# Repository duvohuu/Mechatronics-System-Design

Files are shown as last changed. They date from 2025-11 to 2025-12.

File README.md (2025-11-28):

# BÁO CÁO
- Section → Subsection → Subsubsection → Dot → '-' → '+'

## Cấu trúc thư mục ảnh
Tất cả ảnh đặt trong thư mục chính `pictures/`. Mỗi chương có một thư mục con chứa ảnh của chương đó.

Cấu trúc:
- pictures/
  - section_1/
  - section_2/
  - section_3/
  - ...

Quy ước đặt tên tệp ảnh:
- Định dạng: cx_py_abc.ext
  - c: ký tự 'c' (chỉ section)
  - x: số chương (ví dụ 1, 2, 10)
  - _p: phân cách và chữ 'p' (picture)
  - y: số thứ tự ảnh trong chương (ví dụ 01, 02; khuyến khích 2 chữ số)
  - _abc: mô tả ngắn về nội dung (không dấu, dùng underscore để cách)
  - .ext: phần mở rộng (png, jpg, pdf, ...)

Ví dụ:
- c1_p01_overview.png      (Ảnh 1 của chương 1, mô tả: overview)
- c2_p03_topography.jpg    (Ảnh 3 của chương 2, mô tả: topography)
- c10_p12_cross_section.pdf

## Template cho hình ảnh:
```latex
\begin{figure}[H]
    \centering
    \includegraphics[width=1\textwidth]{pictures/image.png}
    \caption{Mô tả hình ảnh}
    \label{fig:label}
\end{figure}
```

## Template cho bảng:
```latex
\begin{table}[H]
    \centering
    \begin{tabular}{|c|c|c|}
        \hline
        \textbf{Cột 1} & \textbf{Cột 2} & \textbf{Cột 3} \\
        \hline
        Dữ liệu 1 & Dữ liệu 2 & Dữ liệu 3 \\
        \hline
    \end{tabular}
    \caption{Mô tả bảng}
    \label{tab:label}
\end{table}
```

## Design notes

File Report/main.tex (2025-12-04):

\documentclass[12pt,a4paper]{report}
\input{library}
\addbibresource{references.bib} 

%Header
\fancyhead{} % clear all header fields
\fancyhead[L]{
    \begin{tabular}{rl}
        \begin{picture}(15, 15)(0,0)
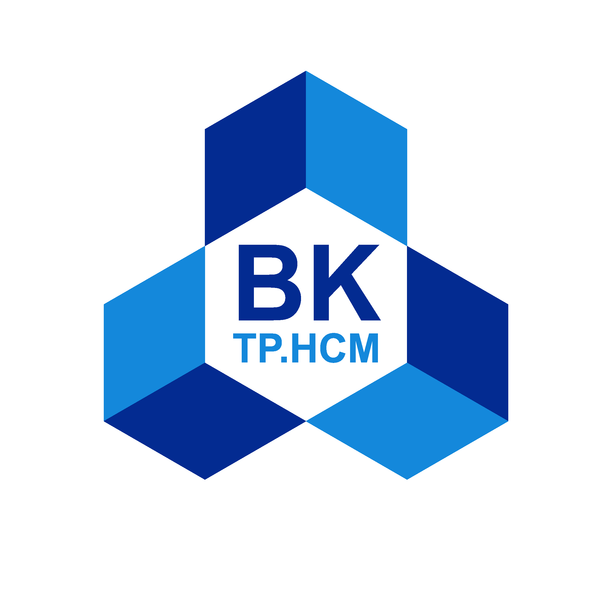
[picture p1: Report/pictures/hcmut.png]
            \put(-15, -15){}
        \end{picture}
        \begin{tabular}{l}
            \textbf{\bf \ttfamily Trường Đại Học Bách Khoa - ĐHQG TP.HCM}\\
            \textbf{\bf \ttfamily Thiết kế hệ thống Cơ điện tử}\\
        \end{tabular} 	
    \end{tabular}
}
\fancyhead[R]{CHƯƠNG \thechapter}
% Footer
\fancyfoot[C]{\thepage} % số trang giữa
\renewcommand{\headrulewidth}{0.3pt}
\renewcommand{\footrulewidth}{0.3pt}

\begin{document}
    \include{titlepage}
    \tableofcontents  
    \listoftables
    \listoffigures
    \newpage
    \normalsize
    \include{chapter1}
    \include{chapter2}
    \include{chapter3}
    \include{chapter4}
    \include{chapter5}
    % \include{chapter6}
    % \appendix
    % \include{appendixA}
    \nocite{*}
    \printbibliography[title={TÀI LIỆU THAM KHẢO}, heading=bibintoc]
\end{document}

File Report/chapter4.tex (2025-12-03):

\chapter{THIẾT KẾ HỆ THỐNG ĐIỆN}
     \hspace*{0.6cm}Yêu cầu thiết kế hệ thống điện dựa trên TCVN-7802-1:2007
     \begin{itemize}
          \item Dải hoạt động của thiết bị đo lường lực: 1.2 kN đến 20 kN
          \item Độ chính xác của thiết bị đo lường lực: $\pm 2 \%$
     \end{itemize}
     \hspace*{0.6cm}Từ việc lựa chọn các phương án điện tổng quát, sơ đồ kết nối điện tổng thể của máy được thể hiện như hình dưới. Sơ đồ thể hiện cách các thiết bị kết nối với nhau, từ nguồn cấp điện đến tủ điều khiển, cảm biến, động cơ. Các model cụ thể cho từng thiết bị cũng như việc tính toán an toàn điện, lựa chọn các thiết bị bảo vệ sẽ được trình bày chi tiết trong chương này.
     \begin{figure}[H]
          \centering
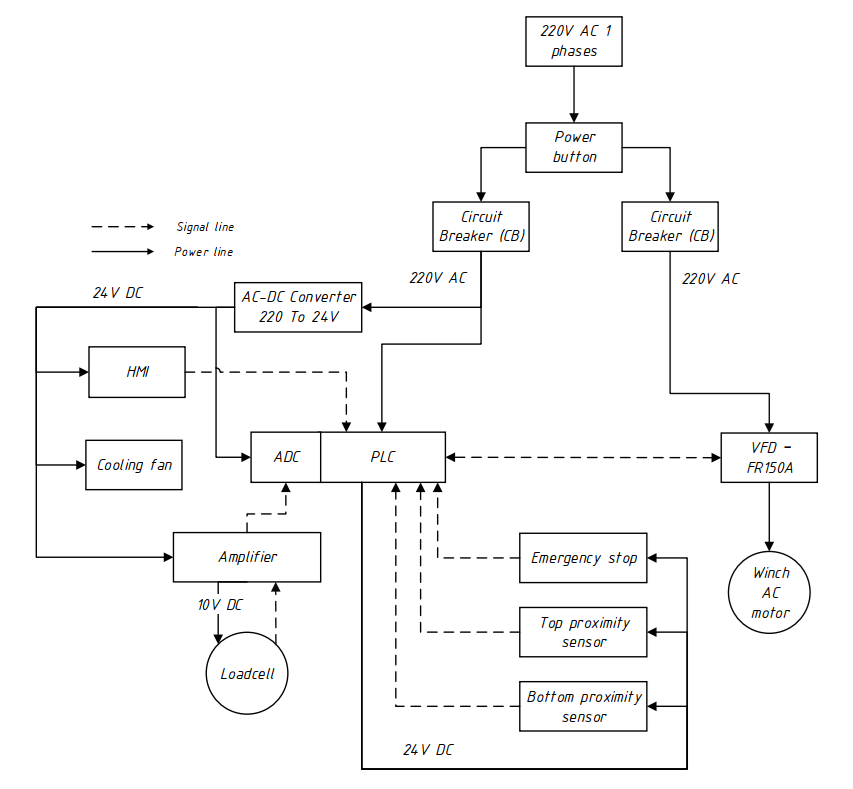
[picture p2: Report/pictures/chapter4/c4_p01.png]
          
          \caption{Sơ đồ điện tổng quan của hệ thống}
          \label{c4_p01}
     \end{figure}
     % Nội dung
     \section{Lựa chọn thiết bị}
          \subsection{Bộ điều khiển PLC và module mở rộng}
               \hspace*{0.6cm}Bộ điều khiển logic khả trình - Programmable Logic Controller (PLC) là trung tâm của hệ thống điều khiển. chịu trách nhiệm xử lý dữ liệu đầu vào, thực thi logic điều khiển và quản lý dữ liệu đầu ra để đảm bảo máy hoạt động chính xác. Để lựa chọn PLC phù hợp, cần xem xét đến các yêu cầu về hiệu suất và khả năng giao tiếp như sau
               \begin{itemize}
                    \item Nguồn cấp: Tương thích với nguồn điện tiêu chuẩn công nghiệp (220 VAC cho nguồn chính, sử dụng bộ chuyển đổi nội hoặc nguồn ngoài cấp 24V DC cho mạch logic).
                    \item I/O: PLC cần có đủ các chân ngõ vào kĩ thuật số (DI) và ngõ ra kĩ thuật số (DO) để kết nối với toàn bộ cảm biến, công tắc và phát tín hiệu điều khiển. Yêu cầu tối thiểu đối với hệ thống: 7 ngõ vào (2 cảm biến tiệm cận, nút nhấn dừng khẩn cấp, tín hiệu từ HMI) và 3 ngõ ra (cho lệnh chạy VFD, điều khiển chiều quay và tốc độ gửi xuống VFD).
                    \item Chức năng đặc biệt: Hỗ trợ bộ đếm tốc độ cao (High-speed Counter) và ngõ ra xung (Pulse Output).
                    \item Truyền thông: Có ít nhất 1 chuẩn giao thức truyền thông (RS232, RS485, RS422, Ethernet) để kết nối với HMI.
                    \item Ngõ vào analog: PLC có khả năng đọc tín hiệu analog, thông qua các ngõ vào có sẵn hoặc module mở rộng nhằm đọc tín hiệu từ bộ khuếch đại tín hiệu loadcell.
                    \item Khả năng xử lí: Cần khả năng xử lí số thực (floating-point) nhằm cho việc tính toán bộ điều khiển PID và các tác vụ xử lí dữ liệu khác.
                    \item Độ tin cậy và giá thành: Độ bền cao trong môi trường công nghiệp, khả năng chống nhiễu tốt và chi phí hợp lí.
               \end{itemize}
               \hspace*{0.6cm}Dựa trên quá trình lựa chọn và đánh giá thỏa mãn các yêu cầu phía trên, PLC MItsubishi FX3U-16MT/ES-A được lựa chọn. Dòng FX3U được đánh giá cao nhờ độ tin cậy, khả năng xử lí và mở rộng trong các hệ thống tự động hóa công nghiệp. Kí hiệu "16MT" trên tên PLC thể hiện PLC có 8 ngõ vào số và 8 ngõ ra transistor, đáp ứng đủ như cầu về các chân I/O. PLC này cũng hỗ trợ xử lí số thực và có sẵn cổng truyền thông RS422 để kết nối với màn hình HMI.
               \newline
               \hspace*{0.6cm}Tuy nhiên dòng FX3U không tích hợp sẵn đầu vào analog, do đó để nhận tín hiệu đầu ra từ bộ khuếch đại tín hiệu loadcell (0 - 10V). Do đó cần thiết phải sử dụng thêm 1 bộ ADC (Analog-to-Digital Converter) mở rộng. Mitsubishi FX3U-3A-ADP được lựa chọn vì nó được thiết kế chuyên dụng để sử dụng với dòng FX3U, cung cấp các kênh ngõ vào analog cần thiết để chuyển đổi tín hiệu analog thành tín hiệu số phục vụ cho việc tính toán trong chương trình điều khiển của PLC.
               \begin{figure}[H]
                    \centering
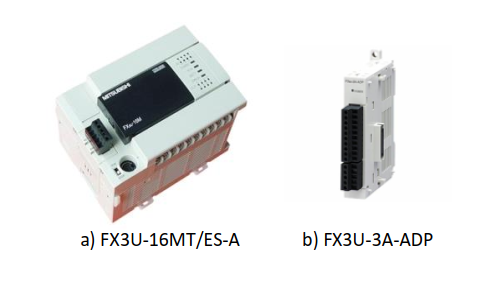
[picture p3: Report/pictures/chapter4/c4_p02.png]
                    
                    \label{c4_p02}
               \end{figure}
               \subsection{Cảm biến loadcell và bộ khuếch đại}
               \hspace*{0.6cm}Độ chính xác khi đo lường lực trong quá trình hoạt động của máy thử thiết bị rất quan trọng, do đó cần 1 cảm biến loadcell đáng tin cậy để chuyển đổi tín hiệu điện thành tín hiệu điện áp, cùng với một bộ khuếch đại tín hiệu để khuếch đại tín hiệu nhằm tương thích với dải đọc analog trên PLC. Các tiêu chí để lựa chọn như sau
               \begin{itemize}
                    \item Tương thích với nguồn cấp: hoạt động với nguồn cấp điện áp 24VDC
                    \item Dải đo: Chịu được lực kéo tĩnh khoảng 15 kN, đồng thời chịu được tải tối đa thiết bị test yêu cầu lên đến 20 kN, tương đương với tải trọng khoảng 2000 kb ($\approx 20 \mathrm{kN}$)
                    \item Độ chính xác: Hệ cảm biến cần có độ chính xác $< \pm 2 \%$
                    \item Tín hiệu ngõ ra: Bộ khuếch đại tín hiệu loadcell cần cung cấp đầu ra là tín hiệu analog chuẩn hóa (0-10 V hoặc 4-20 mA).
               \end{itemize}
               \hspace*{0.6cm}Với những yêu cầu trên, cộng với quyết định sử dụng loadcell loại S ở chương 2 vì phù hợp với thử nghiệm kéo (tensile testing) và dễ dàng lắp đặt, loadcell PT4000 được lựa chọn sử dụng. Loại có định mức từ 2000 kg trở lên đáp ứng được dải tải yêu cầu, đảm bảo độ tin cậy và độ chính xác phù hợp.
               \newline
               \hspace*{0.6cm}Để khuếch đại tín hiệu từ loadcell, lựa chọn bộ khuếch đại KM02. Bộ khuếch đại này hoạt động trong dải điện áp 15-24 VDC. KM02 cung cấp tín hiệu đầu ra có thể cấu hình (0-10 V hoặc 4-20 mA) tương thích với module analog của PLC. Ngoài ra nó còn được tích hợp sẵn các chiết áp để điều chỉnh đầu ra ở các mức ZERO và SPAN, giúp quá trình hiệu chỉnh trở nên đơn giản, chính xác và thuận tiện.
               % figure
          \subsection{Cảm biến tiệm cận}
               \hspace*{0.6cm}Để ngăn ngừa hư hỏng cơ khí và đảm bảo vận hành an toàn, máy phải phát hiện được giới hạn trên và giới hạn dưới của cơ cấu tời (winch mechanism) hoặc các bộ phận chuyển động khác. Cảm biến tiệm cận điện cảm (inductive proximity sensor) là lựa chọn lý tưởng để phát hiện các mục tiêu kim loại mà không cần tiếp xúc vật lý. Các tiêu chí lựa chọn cảm biến này bao gồm:
               \begin{itemize}
                    \item Nguồn: Hoạt động ở 24 V DC, tiêu chuẩn cho các hệ thống điều khiển công nghiệp.
                    \item Loại đầu ra: Cấu hình PNP 3 dây, phù hợp để kết nối với các module đầu vào sourcing của PLC Mitsubishi.
                    \item Khoảng cách cảm biến: Khoảng 5–10 mm để đảm bảo hoạt động tin cậy mà không yêu cầu định vị quá chính xác.
                    \item Mục tiêu phát hiện: Phải phát hiện đáng tin cậy các vật thể kim loại.
                    \item Cách lắp đặt: Thân trụ ren (loại gắn bằng đai ốc) để dễ dàng lắp đặt cơ khí.
                    \item Độ bền và tính sẵn có: Chịu được môi trường công nghiệp khắc nghiệt, sử dụng thường xuyên và dễ thay thế.
               \end{itemize}
               \hspace*{0.6cm}Dựa trên các tiêu chí trên, cảm biến tiệm cận điện cảm model LJ18A3-8-Z/BY PNP đã được lựa chọn. Model này có thân ren M18 tiện lợi cho việc lắp đặt, hoạt động với nguồn 24 V DC, đầu ra loại PNP (lưu ý: có thể kết nối tương thích với đầu vào sourcing của PLC bằng cách đấu nối phù hợp). Khoảng cách cảm biến 8 mm nằm trong dải mong muốn để phát hiện các chốt chặn kim loại. Cảm biến này có giá thành hợp lý, được sử dụng rộng rãi và chứng minh độ tin cậy cao trong môi trường công nghiệp.
          \subsection{Biến tần}
               \hspace*{0.6cm}Máy thử nghiệm sử dụng tời điện được dẫn động bởi động cơ điện AC nhằm tạo ra và duy trì lực kéo. Do yêu cầu của bài thử nghiệm cần tăng lực từ từ (trong vòng 240s) và duy trì (trong vòng 180s), phương pháp điều khiển ON/OFF đơn giản không thể đáp ứng. Vì vậy, việc sử dụng biến tần (VFD: Variable Frequency Drive) là cần thiết do mục đích điều khiển chính xác tốc độ, moment, xoắn, việc gia tốc, giảm tốc và chiều quay của động cơ dựa trên giá trị setpoint từ bộ điều khiển PID.
               \newline
               \hspace*{0.6cm}Các yêu cầu kĩ thuật:
               \begin{itemize}
                    \item Tương thích với nguồn: Biến tần hỗ trợ nguồn 1 pha 220 VAC.
                    \item Công suất định mức: phải đủ khả năng dẫn động động cơ điện công suất 1.4 kW cho tời kéo. 
                    \item Khả năng tích hợp với PLC: Hỗ trợ giao tiếp số (ưu tiên giao thức Modbus) để giao tiếp lệnh điều khiển và dữ liệu phản hồi giữa PLC và biến tần.                 
               \end{itemize}                
               \hspace*{0.6cm}Mẫu biến tần được lựa chọn là FR150A-2S-1.5B-H của hãng Frecon Electric, đáp ứng được tất cả các yêu cầu trên. Biến tần này có công suất định mức 1.5 kW, hoạt động với nguồn vào 220 V một pha, đủ để dẫn động động cơ tời 1.4 kW.
               Đặc biệt quan trọng, model này hỗ trợ giao thức Modbus RTU qua RS485, cho phép PLC Mitsubishi FX3U gửi các lệnh điều khiển (như chạy/dừng, đặt tần số, đặt hướng quay...) và nhận dữ liệu phản hồi (tốc độ động cơ thực tế, dòng điện, trạng thái lỗi, v.v.).
               Nhờ đó, hệ thống đạt được khả năng điều khiển lực tời chính xác, lập trình linh hoạt và vận hành ổn định, đáng tin cậy.
          \subsection{HMI}
               \hspace*{0.6cm}Giao diện người-máy HMI (Human-Machine Interface) cho phép người vận hành thực hiện các thao tác với hệ thống như khởi động/dừng quá trình thử nghiệm, cài đặt các thông số bộ điều khiển (hệ số PID, các hệ số hiệu chỉnh, \dots), theo dõi dữ liệu thời gian thực (giá trị lực, thời gian, trạng thái cảm biến), hiển thị đồ thị kết quả thử nghiệm (đồ thị lực theo thời gian). Các tiêu chí để lựa chọn HMI bao gồm:
               \begin{itemize}
                    \item Giao tiếp với PLC: Đảm bảo kết nối được với PLC Mitsubishi FX3U-16MT/ES-A.
                    \item Màn hình hiển thị: Kích thước và độ phân giải đủ lớn, hỗ trợ cảm ứng để dễ dàng thao tác.
                    \item Phần mềm: Dễ dàng sử dụng trong việc thiết kế giao diện và gửi nhận dữ liệu với PLC. 
               \end{itemize}
               Từ các tiêu chí đó, lựa chọn HMI Weintek MT607iH. HMI có màn hình 7 inch, độ phân giải của màn hình là $800 \times 400$. Hỗ trợ kết nối với PLCs qua giao thức RS232 và RS485. Cấu hình HMI thực hiện thông qua phần mềm EasyBuilder Pro (hoặc EasyBuilder 8000) giúp thiết kế giao diện HMI dễ dàng.
     \section{Tính toán nguồn và an toàn thiết bị điện}
          \subsection{Nguồn động lực}
          \hspace*{0.6cm}Từ sơ đồ khối điện tổng quát, các nguồn chính là: nguồn xoay chiều 1 pha 220 VAC cho tời điện và biến tần, nguồn 1 chiều 24 VDC cho các thiết bị còn lại.
          \subsection{Tính toán dây dẫn}
          \hspace*{0.6cm}Dựa trên các thiết bị dã chọn, tiến hành tính toán dòng điện, lựa chọn dây dẫn, các thiết bị bảo vệ. Bảng dưới đây liệt kê các thiết bị điện trong hệ thống, số lượng và công suất tiêu thụ điện
          \begin{table}[h!]
               \caption{Danh sách thiết bị}
               \label{tab:device_list}
               \centering
               \begin{tabular}{|c|l|c|c|c|}
               \hline
               \textbf{} & \centering\textbf{Tên thiết bị} & \textbf{Số lượng} & \textbf{Nguồn} & \textbf{Công suất tiêu thụ} \\ \hline

               1 & PLC FX3U-16MT/ES-A & 1 & \multirow{5}{*}{24V DC} & 30\,W \\ \cline{1-3}\cline{5-5}

               2 & Module FX3U–3A–ADP & 1 &  & 5\,W \\ \cline{1-3}\cline{5-5}

               3 & Weintek HMI model MT607iH & 1 &  & 6\,W \\ \cline{1-3}\cline{5-5}

               4 & Bộ khuếch đại BRT RW-ST01A & 1 &  & 1.5\,W \\ \cline{1-3}\cline{5-5}

               5 & Cảm biến tiệm cận LJ18A3-8-Z/BX NPN & 1 &  & 7.2\,W \\ \hline

               6 & Tời điện 3WG4 Atlas II 
               & 1 & \multirow{2}{*}{220V AC} & 1.4\,kW \\ \cline{1-1}\cline{2-3}\cline{5-5}

               7 & Biến tần FR150A-2S-1.5B-H & 1 &  & 1.5\,kW \\ \hline
               \end{tabular}
          \end{table}
          \hspace*{0.6cm}Dòng trong mạch điều khiển
          \begin{equation}
               I_{\text{control}} = \dfrac{P}{U} = \dfrac{30 + 5 + 6 + 1.5 + 7.2}{24} \approx 2.07 \,\mathrm{A}
               \label{c4_eq01}
          \end{equation}
          \hspace*{0.6cm}Đối với mạch điều khiển, sử dụng bộ chuyển đổi nguồn 24V 3A 72W.
          \newline
          \hspace*{0.6cm}Tính toán dòng cho CB trong mạch điều khiển
          \begin{equation}
               I_{\text{control\_CB}} = (1.2 \div 1.5)I_{\text{control}} = 2.07 \times 1.5 \approx 3.105 \,\mathrm{A}
               \label{c4_eq02}
          \end{equation}
          \hspace*{0.6cm}Với dòng như vậy, lựa chọn MCB Chint NXB-63 C6 2P làm CB cho mạch điều khiển.
          \newline
          \hspace*{0.6cm}Đối với mạch động lực, dòng đầu vào định mức của biến tần Frecon FR150A-2S-1.5B-H là 15.7 A, tiến hành tính toán dòng cho CB mạch động lực 
          \begin{equation}
               I_{\text{power\_CB}}  = (2 \div 3)I_{\text{power}} = 15.7 \times 3 = 47.1 \,\mathrm{A}
               \label{c4_eq03}
          \end{equation}
          \hspace*{0.6cm}Với dòng tính toán, lựa chọn MCB 2P 50A, 63A 6kA Panasonic làm CB cho mạch động lực.
          \newline
          \hspace*{0.6cm}Về dây dẫn đấu nối trong mạch, tra theo Catalogue của Cadivi, các loại dây sử dụng được liệt kê ở bảng sau
          \begin{table}[H]
               \caption{Danh sách các loại dây sử dụng}
               \label{tab:wire_list}
               \centering
               \begin{tabular}{|l|c|}
               \hline
               \textbf{Chức năng dây} & \textbf{Loại dây} \\ \hline

               Dây cho 220VAC (Dây nóng – L) & VCm-2.5 \\ \hline
               Dây cho 220VAC (Dây trung tính – N) & VCm-2.5 \\ \hline
               Dây nối đất (PE) & VCm-1 \\ \hline
               Dây 24VDC (Dương) & VCm-1 \\ \hline
               Dây 24VDC (Âm) & VCm-1 \\ \hline
               Dây trong mạch điều khiển & VCm-1 \\ \hline
               \end{tabular}
          \end{table}

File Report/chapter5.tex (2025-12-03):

\chapter{THIẾT KẾ BỘ ĐIỀU KHIỂN}
    \textbf{Yêu cầu hệ thống}: Có khả năng tăng lực lên 15 kN trong vòng 240 giây và duy trì lực đó trong 180 giây.
    \section{Chương trình chính}
        \hspace*{0.6cm}Trong số các phương án được đề xuất, sơ đồ thuật toán của bộ điều khiển chính đã lựa chọn thể hiện đầy đủ các chức năng cần thiết cho quá trình vận hành của máy. Sơ đồ cung cấp cái nhìn rõ ràng và chi tiết về trình tự làm việc, giúp đảm bảo các bước được tổ chức logic, dễ theo dõi và tuân thủ đúng tiêu chuẩn yêu cầu. Nhờ đó, hệ thống vận hành ổn định, nhất quán và đạt độ chính xác cao.
        \begin{figure}[H]
            \centering
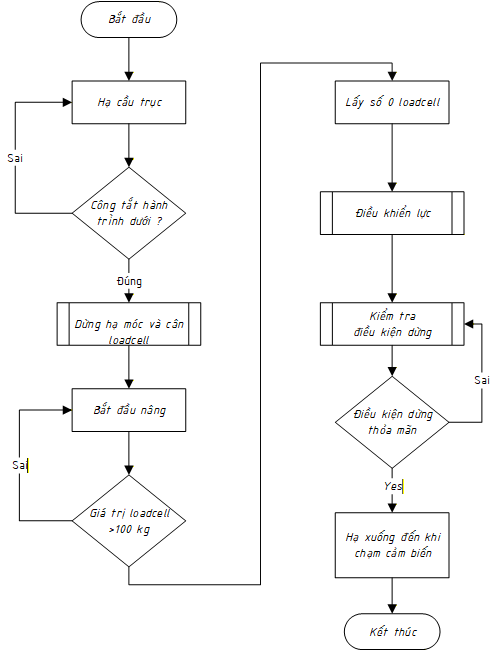
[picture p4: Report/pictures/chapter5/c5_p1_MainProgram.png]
            
            \caption{Sơ đồ chương trình chính}
            \label{fig:main_program}
        \end{figure}
        
        Chu trình hoạt động của máy thử độ bền tĩnh bắt đầu bằng lệnh hạ cụm nâng chính (cầu trục). Việc hạ diễn ra cho đến khi cảm biến hành trình dưới được kích hoạt, cho biết móc treo đã ở đúng vị trí thấp an toàn để gắn mẫu thử — ma nơ canh 100 kg. Khi cảm biến này báo hiệu, hệ thống lập tức dừng hạ.

        Tiếp theo, hệ thống tiến hành hiệu chỉnh loadcell về mốc zero, sử dụng trọng lượng của ma nơ canh làm giá trị chuẩn ban đầu. Việc hiệu chuẩn này giúp các phép đo lực sau đó chỉ phản ánh lực kéo tác dụng lên dây an toàn, không bao gồm trọng lượng của mẫu thử.

        Khi hiệu chuẩn hoàn tất, máy chuyển sang giai đoạn nâng tải. Tời bắt đầu kéo ma nơ canh lên, tạo lực căng trên dây an toàn. Hệ thống đồng thời kiểm tra giá trị loadcell để xem lực đo được có vượt mức ban đầu (100 kg) hay chưa. Nếu lực vượt ngưỡng này, điều đó chứng tỏ dây an toàn đã bắt đầu chịu lực thử.

        Từ thời điểm đó, bộ điều khiển sử dụng phản hồi từ loadcell và điều khiển động cơ tời thông qua VFD để tăng dần lực kéo, theo đúng yêu cầu tiêu chuẩn, cho đến khi đạt 15 kN. Khi lực mục tiêu đạt được, hệ thống chuyển sang giai đoạn giữ lực, duy trì tải 15 kN trong 3 phút.

        Trong suốt quá trình tăng lực và giữ lực, thuật toán liên tục kiểm tra an toàn, đặc biệt là giám sát cảm biến hành trình trên nhằm tránh vượt quá giới hạn nâng. Nếu cảm biến này được kích hoạt hoặc có điều kiện dừng khác, hệ thống lập tức ngừng hoạt động nâng hoặc giữ lực và có thể thực hiện hạ tải an toàn, đưa cơ cấu về vị trí thấp, thường được xác định lại bằng cảm biến dưới.

        Khi thời gian thử nghiệm kết thúc (sau giai đoạn giữ lực), và trong trường hợp không có sự cố an toàn nào xảy ra trước đó, hệ thống sẽ hạ tải và trở về trạng thái nghỉ, đánh dấu kết thúc chu trình chương trình chính.
    \section{Chuơng trình con}
        \subsection{Dừng quá trình hạ và thực hiện lấy 0 cho loadcell}
            \begin{figure}[H]
                \centering
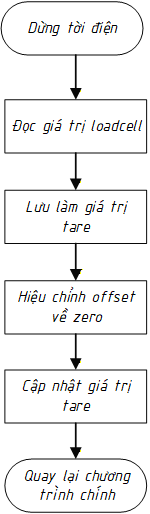
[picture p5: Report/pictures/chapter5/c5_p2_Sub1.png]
                
                \caption{Sơ đồ chương trình con lấy số 0 cho loadcell}
                \label{fig:tare_loadcell}
            \end{figure}
            \hspace*{0.6cm}Chương trình con này mô tả quy trình hiệu chuẩn loadcell nhằm thiết lập mốc zero chính xác trước khi bắt đầu áp dụng tải thử. Trước hết, hệ thống cần đạt trạng thái ổn định để đảm bảo phép đo chính xác, do đó bước đầu tiên là “Dừng tời điện”. Việc này loại bỏ hoàn toàn chuyển động và rung động có thể làm sai lệch giá trị đo của loadcell.

            Khi cơ cấu đã đứng yên, chương trình thực hiện bước “Đọc giá trị loadcell”. Tại thời điểm này, loadcell ghi nhận trọng lượng tĩnh đang treo trên nó, thường là ma nơ canh 100 kg được gắn vào dây an toàn.

            Giá trị trọng lượng ban đầu này được lưu tạm thời làm “Giá trị lấy số 0”. Tiếp theo, hệ thống tiến hành “Hiệu chỉnh offset về zero”, điều chỉnh tín hiệu loadcell hoặc cách hệ thống xử lý tín hiệu để trọng lượng của ma nơ canh được xem là mốc zero cho toàn bộ các phép đo lực tiếp theo. Điều này có nghĩa là trọng lượng ban đầu sẽ được loại bỏ hoàn toàn khi hệ thống tính toán lực thử.

            Sau đó, bước “Cập nhật giá trị lấy số 0” xác nhận rằng hiệu chỉnh đã được ghi nhận vào bộ nhớ, đảm bảo mốc zero mới được áp dụng chính thức. Khi quá trình lấy số 0 và hiệu chỉnh offset hoàn tất, chương trình con kết thúc và hệ thống trở lại chương trình chính, sẵn sàng thực hiện các bước tiếp theo như nâng tải và tăng lực thử với một hệ thống đo lực đã được hiệu chuẩn chính xác.
        % \subsection{Bắt đầu nâng và tăng lực}
        %     \begin{figure}[H]
        %         \centering
        %         \includegraphics[width=0.3\textwidth]{pictures/chapter5/c5_p3_Sub2.png}
        %         \caption{Sơ đồ chương trình con bắt đầu nâng và tăng lực}
        %         \label{fig:start_lifting}
        %     \end{figure}
        %     \hspace*{0.6cm}Phần này của quá trình điều khiển tập trung vào giai đoạn máy tăng lực kéo tác dụng lên dây an toàn cho đến khi đạt giá trị mục tiêu. Quy trình bắt đầu với lệnh “Bắt đầu nâng”, kích hoạt cơ cấu tời di chuyển lên trên. Ngay sau đó, hệ thống đọc giá trị lực hiện tại từ cảm biến loadcell để lấy dữ liệu đo thực tế.

        %     Giá trị lực đo được sẽ được so sánh với giá trị đặt (setpoint) hoặc quỹ đạo tăng lực theo yêu cầu trong bộ điều khiển PID. Bộ điều khiển PID tính toán sai lệch (error) giữa lực thực đo và lực cần đạt tại thời điểm đó. Dựa trên sai lệch này, PID xác định mức điều chỉnh cần thiết để đưa lực thực tế tiệm cận giá trị mục tiêu. Việc điều chỉnh này thường được thực hiện thông qua thay đổi tốc độ hoặc mô-men của động cơ tời.

        %     Tín hiệu điều khiển đã được tính toán bởi PID sau đó được gửi tới tời điện, thông qua biến tần (VFD). Tín hiệu này quyết định cách tời vận hành — tăng tốc, giảm tốc hoặc giữ tốc độ — nhằm đảm bảo lực được tăng theo đúng quỹ đạo đã định.

        %     Sau khi tời nhận và thực hiện lệnh, hệ thống chuyển sang bước kiểm tra điều kiện: liệu lực hiện tại đã đạt giá trị mục tiêu 1500 kg hay chưa. Nếu lực vẫn chưa đạt, chu trình sẽ được lặp lại: đọc lại lực hiện tại, tính toán lại sai lệch PID, điều chỉnh tốc độ nâng dựa trên đầu ra mới của PID, gửi tín hiệu điều khiển mới đến tời và kiểm tra lại lực.

        %     Chu trình điều khiển vòng kín này diễn ra liên tục, thực hiện các điều chỉnh nhỏ nhưng chính xác để đảm bảo lực tăng mượt mà và chính xác tới mức 1500 kg. Khi loadcell xác nhận rằng lực đặt đã đạt 1500 kg, điều kiện dừng được thỏa mãn, vòng lặp kết thúc và chương trình thoát khỏi chương trình con này, quay trở lại chương trình chính để tiếp tục bước giữ lực theo yêu cầu thử nghiệm.
        \subsection{Điều khiển lực}
            \begin{figure}[H]
                \centering
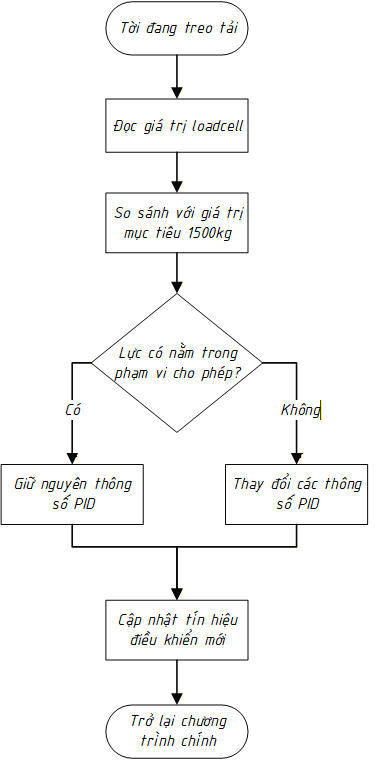
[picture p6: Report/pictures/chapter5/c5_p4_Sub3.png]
                
                \caption{Sơ đồ chương trình con điều khiển lực}
                \label{fig:force_control}
            \end{figure}    

            \hspace*{0.6cm}Phần này của thuật toán mô tả cách hệ thống duy trì lực mục tiêu trong suốt giai đoạn giữ tải. Vòng lặp bắt đầu bằng việc “Đọc giá trị loadcell” để lấy lực hiện tại do tời tạo ra. Giá trị đo được sau đó được dùng ngay để so sánh với lực mục tiêu 1500 kg.

            Dựa trên kết quả so sánh, hệ thống đưa ra quyết định tại bước “Lực có nằm trong phạm vi cho phép không?”. Bước này kiểm tra xem lực đo được có lệch khỏi giá trị 1500 kg quá giới hạn sai số cho phép hay không. Nếu lực nằm trong vùng sai số chấp nhận được (nhánh “Yes”), điều đó nghĩa là hệ thống đang giữ lực ổn định, vì vậy thuật toán sẽ giữ nguyên các thông số PID hiện tại mà không cần điều chỉnh.

            Ngược lại, nếu lực đo được nằm ngoài phạm vi cho phép (nhánh “No”), tức là lực đã bị giảm hoặc tăng quá mức so với 1500 kg, hệ thống phải thực hiện hiệu chỉnh. Thuật toán chuyển sang bước “Thay đổi giá trị PID để đạt lực mong muốn”, nghĩa là bộ điều khiển PID sẽ tính toán lại dựa trên sai lệch hiện tại để xác định mức điều chỉnh phù hợp nhằm đưa lực quay trở về giá trị mục tiêu.

            Dù PID được giữ nguyên hay thay đổi, bước tiếp theo luôn là “Cập nhật thông số điều khiển cho tời điện”, gửi giá trị điều khiển mới nhất đến tời thông qua biến tần VFD. Sau khi cập nhật lệnh điều khiển, quá trình quay lại bước đầu tiên — đọc lại giá trị loadcell — và tiếp tục lặp lại toàn bộ chu trình.

            Vòng điều khiển kín này được duy trì liên tục, giúp hệ thống giám sát và hiệu chỉnh lực theo thời gian thực, đảm bảo lực 1500 kg được giữ ổn định và chính xác trong suốt thời gian yêu cầu của bài thử độ bền tĩnh.
        \subsection{Điều kiện dừng}
            \begin{figure}[H]
                \centering
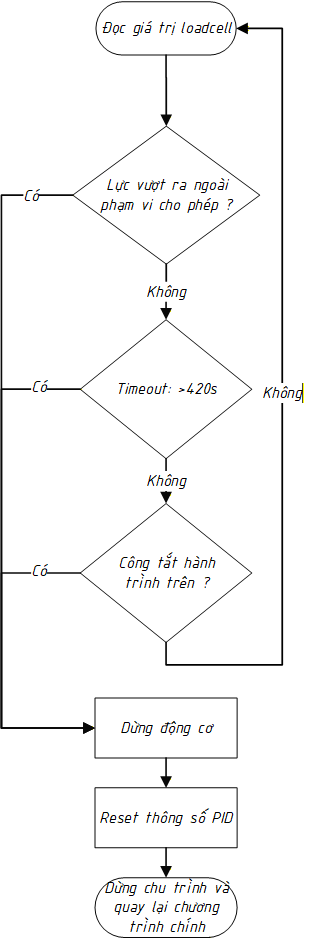
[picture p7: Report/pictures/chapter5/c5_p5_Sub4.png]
                
                \caption{Sơ đồ chương trình con điều kiện dừng}
                \label{fig:stop_condition}
            \end{figure}
            \hspace*{0.6cm}Phần này của thuật toán điều khiển tập trung vào việc giám sát các điều kiện buộc hệ thống phải dừng động cơ và kết thúc giai đoạn thử hiện tại.

            Trước hết, hệ thống kiểm tra xem lực có nằm ngoài phạm vi cho phép hay không. Nếu lực vượt quá giới hạn sai số, thuật toán lập tức thực hiện lệnh “Dừng động cơ”, chấm dứt hoạt động của tời để đảm bảo an toàn.

            Nếu lực vẫn nằm trong phạm vi cho phép, hệ thống tiếp tục kiểm tra hai điều kiện khác. Điều kiện đầu tiên là thời gian duy trì lực (Timeout) xem đã vượt quá 180 giây hay chưa — đây là thời gian giữ lực 3 phút theo yêu cầu của tiêu chuẩn TCVN. Nếu thời gian đã đạt hoặc vượt mức này, hệ thống ra lệnh “Dừng động cơ”, đánh dấu giai đoạn giữ lực đã hoàn tất thành công.

            Song song hoặc ngay sau đó, hệ thống kiểm tra tín hiệu từ cảm biến hành trình. Đây có thể là cảm biến hành trình trên hoặc một cảm biến an toàn khác. Nếu cảm biến được kích hoạt, thuật toán coi đây là sự kiện an toàn hoặc chạm giới hạn cơ khí và thực hiện “Dừng động cơ” ngay lập tức.

            Như vậy, động cơ sẽ dừng hoạt động nếu xảy ra một trong ba tình huống:
            \begin{itemize}
                \item Lực ra khỏi phạm vi cho phép.
                \item Thời gian giữ lực đã đủ 180 giây
                \item Cảm biến hành trình/sensor an toàn được kích hoạt.
            \end{itemize}
            \hspace*{0.6cm}Sau khi lệnh “Dừng động cơ” được thực thi, hệ thống tiến hành các thao tác kết thúc, bao gồm “Reset thông số PID” để xóa hoặc thiết lập lại các giá trị PID đã dùng trong quá trình điều khiển lực. Cuối cùng, thuật toán kết thúc với bước “Dừng quá trình và quay lại chương trình chính”, báo hiệu rằng giai đoạn giữ lực đã kết thúc và hệ thống trở lại chu trình vận hành tổng thể của máy thử.
    \section{Bộ điều khiển PID}
        \subsection{Yêu cầu của tiêu chuẩn TCVN 7802}
            \hspace*{0.6cm}Theo tiêu chuẩn TCVN-7802-1:2007, lực tăng theo thời gian phải tuân theo biên dạng thể hiện trong sơ đồ dưới đây:
            \begin{figure}[H]
                \centering
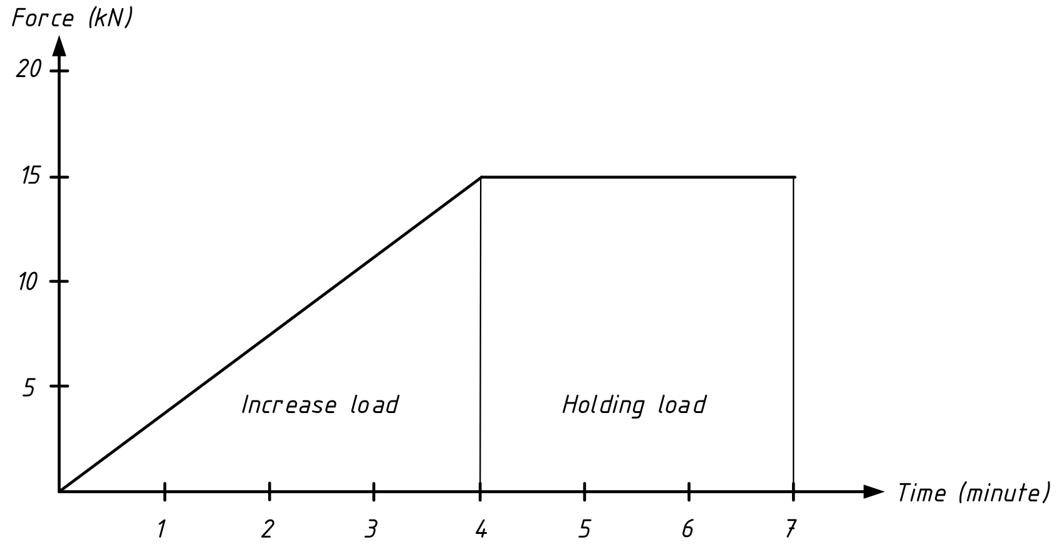
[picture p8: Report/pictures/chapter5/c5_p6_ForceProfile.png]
                
                \caption{Profile Lực}
                \label{fig:PID_requirement}
            \end{figure}
        \subsection{Đặc tính cơ học của dây đai và ảnh hưởng đến điều khiển}

            \hspace*{0.6cm}Trong giai đoạn tăng lực, đặc tính vật liệu của dây đai khiến độ cứng của nó thay đổi khi lực
            đạt đến một ngưỡng ứng suất nhất định. Sự thay đổi này có thể xảy ra trong cả hai giai đoạn:
            tăng lực hoặc giữ lực, tùy thuộc vào đặc tính vật liệu của dây đai.

            Do dây đai là vật liệu đàn hồi, nó tuân theo Định luật Hooke và có thể được mô hình hóa như
            một lò xo có độ cứng thay đổi theo mức độ biến dạng.

            \subsubsection*{Định luật Hooke}

                \hspace*{0.6cm}Định luật Hooke phát biểu rằng trong giới hạn đàn hồi, độ lớn của lực đàn hồi tỉ lệ thuận với
                độ biến dạng của dây đai:

                \begin{equation}
                    F_{\mathrm{đh}} = k \cdot |\Delta l|
                \end{equation}

                Trong đó:

                \begin{itemize}
                    \item $k$: độ cứng (hệ số đàn hồi) của dây đai,
                    \item $\Delta l$: độ biến dạng của dây đai.
                \end{itemize}

            \subsubsection*{Biến dạng đàn hồi}

                \hspace*{0.6cm}Một vật liệu rắn được xem là chịu biến dạng đàn hồi khi nó bị tác dụng bởi một tải nhỏ (kéo
                hoặc nén) và có thể trở lại trạng thái ban đầu khi tải được loại bỏ. Khi ứng suất và biến dạng
                nhỏ, quan hệ ứng suất – biến dạng gần như tuyến tính và được mô tả bởi Định luật Hooke, với
                hằng số tỉ lệ là môđun Young.

                \begin{figure}[H]
                    \centering
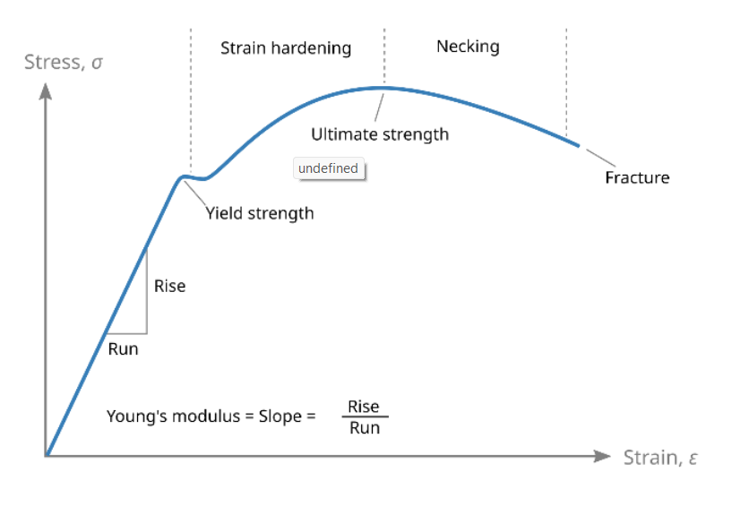
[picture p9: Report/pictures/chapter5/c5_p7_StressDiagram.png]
                    
                    \caption{Biểu đồ ứng suất}
                    \label{fig:elastic_deformation}
                \end{figure}

                Môđun Young càng lớn, vật liệu càng cần nhiều ứng suất để tạo ra cùng một mức biến dạng.
                Một vật hoàn toàn cứng sẽ có môđun Young tiến tới vô hạn, trong khi vật liệu rất mềm (như
                chất lỏng) có môđun Young xấp xỉ bằng 0.

                Điều này có nghĩa là ở mức ứng suất nhỏ, vật liệu tuân theo quan hệ tuyến tính. Tuy nhiên,
                khi ứng suất lớn hơn — như trong quá trình thử dây đai — vật liệu sẽ có xu hướng phi tuyến và
                không còn tuân theo Định luật Hooke một cách chính xác.

            \subsubsection*{Ảnh hưởng đến điều khiển}

                \hspace*{0.6cm}Trong cả hai giai đoạn tăng lực và giữ lực, hiện tượng trượt có thể xảy ra, dẫn đến mất lực tại
                loadcell. Khi đó, hệ thống phải thực hiện bù lực bằng cách điều chỉnh các tham số PID, đặc biệt
                khi dây đai tiến gần đến giới hạn đàn hồi của vật liệu. Việc tinh chỉnh PID là rất quan trọng để
                duy trì lực ổn định và chính xác trong suốt quá trình thử nghiệm.
        \subsection{Bộ điều khiển PID trong PLC Mitsubishi FX3U}
            \begin{figure}[H]
                \centering
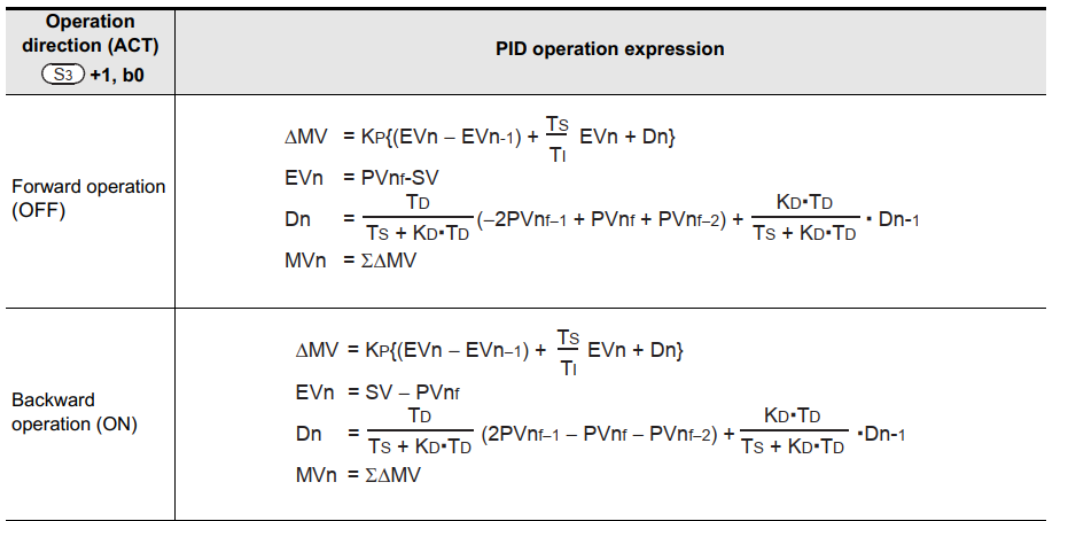
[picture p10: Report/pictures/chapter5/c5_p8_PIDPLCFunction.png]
                
                \caption{Khối PID trong PLC Mitsubishi FX3U}
                \label{fig:pid_block}
            \end{figure}

            \hspace*{0.6cm}Hệ thống sử dụng bộ điều khiển PID tích hợp sẵn trên PLC Mitsubishi FX3U. Thuật toán PID
            được thực hiện theo dạng \textit{gia tăng} (incremental form, hay còn gọi là \textit{velocity form}).
            Cách tiếp cận này tính toán \textbf{sự thay đổi} của tín hiệu điều khiển $\Delta MV$ tại mỗi chu kỳ quét,
            thay vì tính giá trị tuyệt đối của tín hiệu điều khiển.

            Cấu trúc này mang lại nhiều ưu điểm như: giảm hiện tượng \textit{windup} của thành phần tích phân,
            và giúp chuyển đổi giữa các chế độ điều khiển được mượt mà hơn.

            Trong quá trình vận hành, tín hiệu từ loadcell được khuếch đại và đọc trực tiếp bởi module
            chuyển đổi A/D FX3U--3ADP. Giá trị thu được $PV_n$ được đưa thẳng vào thuật toán PID.

            Bộ điều khiển được cấu hình ở chế độ \textit{backward operation} theo hướng dẫn của FX3U.  
            Theo tài liệu của Mitsubishi, bộ PID tuân theo công thức:

            \begin{equation}
            \Delta MV = K_p \left[ (EV_n - EV_{n-1}) + 
            \frac{T_S}{T_I} EV_n + D_n \right]
            \end{equation}

            Trong đó:

            \begin{itemize}
                \item $\Delta MV$: lượng thay đổi của tín hiệu điều khiển,
                \item $K_p$: hệ số khuếch đại tỉ lệ,
                \item $EV_n$: sai lệch tại chu kỳ lấy mẫu hiện tại,
                \item $EV_{n-1}$: sai lệch tại chu kỳ trước,
                \item $T_S$: chu kỳ lấy mẫu,
                \item $T_I$: hằng số thời gian tích phân,
                \item $D_n$: thành phần vi phân.
            \end{itemize}

            \subsubsection*{Tính toán sai lệch}

                \begin{equation}
                EV_n = PV_{nf} - SV
                \end{equation}

                Trong đó:

                \begin{itemize}
                    \item $PV_{nf}$: giá trị quá trình hiện tại,
                    \item $SV$: giá trị đặt.
                \end{itemize}

                \subsubsection*{Tính toán thành phần vi phân}

                \begin{equation}
                D_n = \frac{T_D}{T_S + K_D T_D}
                \left( 2PV_{nf-1} - PV_{nf} - PV_{nf-2} \right)
                + \frac{K_D T_D}{T_S + K_D T_D} D_{n-1}
                \end{equation}

                Trong đó:

                \begin{itemize}
                    \item $D_n$: thành phần vi phân tại thời điểm $n$,
                    \item $D_{n-1}$: thành phần vi phân tại thời điểm $n-1$,
                    \item $T_D$: hằng số thời gian vi phân,
                    \item $K_D$: hệ số khuếch đại vi phân,
                    \item $PV_{nf-1}$: giá trị quá trình ở chu kỳ trước,
                    \item $PV_{nf-2}$: giá trị quá trình ở hai chu kỳ trước.
                \end{itemize}

            \subsubsection*{Tín hiệu điều khiển tại thời điểm n}

                \begin{equation}
                MV_n = \sum \Delta MV
                \end{equation}

                \subsubsection*{Ghi chú về các tham số quan trọng}
                \begin{itemize}
                    \item \textbf{Thời gian tích phân $T_I$}  
                    Là thời gian cần thiết để thành phần tích phân tích lũy đủ để bù bằng với đầu ra của thành phần tỉ lệ.
                    Thời gian này cho biết tốc độ mà thành phần tích phân phản ứng với sai lệch.

                    \item \textbf{Hệ số vi phân $K_D$}  
                    Ảnh hưởng đến độ nhạy của thành phần vi phân:  
                    \begin{itemize}
                        \item $K_D$ nhỏ → phản ứng nhanh nhưng nhạy với nhiễu,
                        \item $K_D$ lớn → phản ứng chậm nhưng lọc nhiễu tốt hơn.
                    \end{itemize}

                    \item \textbf{Thời gian vi phân $T_D$}  
                    \begin{itemize}
                        \item $T_D$ nhỏ → lọc yếu, phản ứng nhanh nhưng dễ khuếch đại dao động nhỏ,
                        \item $T_D$ lớn → lọc mạnh, chỉ phản ứng với thay đổi lớn và giảm nhiễu tần số cao.
                    \end{itemize}

                    Nếu tín hiệu nhiễu nhỏ, ta có thể tắt thành phần vi phân bằng cách đặt $T_D = 0$ để đạt phản ứng nhanh.
                \end{itemize}
        \subsection{Phương pháp hiệu chỉnh PID bằng Ziegler--Nichols}

            \hspace*{0.6cm}Để hiệu chỉnh các tham số của bộ điều khiển PID, hệ thống áp dụng phương pháp 
            Ziegler--Nichols, một kỹ thuật được sử dụng rộng rãi trong điều khiển tự động. 
            Phương pháp này dựa trên việc xác định \textit{hệ số khuếch đại tới hạn} $K_u$ và 
            \textit{chu kỳ dao động tới hạn} $P_u$ của hệ thống.

            Các thí nghiệm được thực hiện trực tiếp trên hệ thống bằng cách đặt bộ điều khiển ở chế độ 
            tỉ lệ (P-mode) và tăng dần hệ số $K_p$ cho đến khi hệ thống xuất hiện dao động duy trì. 
            Các giá trị $K_u$ và $P_u$ thu được cho ba khoảng lực $k$ được trình bày như sau:

            \begin{itemize}
                \item Với $k < 700$: $K_u = 833.3$, \; $P_u = 0.4 \, \text{s}$
                \item Với $700 < k < 1000$: $K_u = 1000$, \; $P_u = 0.6 \, \text{s}$
                \item Với $k > 1000$: $K_u = 1166.77$, \; $P_u = 0.8 \, \text{s}$
            \end{itemize}

            Việc chia thành ba khoảng lực khác nhau xuất phát từ đặc tính cơ học của dây đai, vốn biến đổi 
            đáng kể theo mức lực tác dụng. Do đó, các tham số PID tương ứng cũng phải được hiệu chỉnh 
            khác nhau để đảm bảo hệ thống duy trì được tính ổn định, độ chính xác và khả năng đáp ứng, 
            phù hợp với yêu cầu của tiêu chuẩn TCVN 7802-1:2007 về thử độ bền tĩnh dây an toàn.

            \subsubsection*{Tính toán tham số PID theo Ziegler--Nichols}

            \hspace*{0.6cm}Dựa vào công thức của Ziegler--Nichols, các tham số PID ban đầu được tính như sau:\\

            \textbf{Với $k < 700$:}
            \begin{itemize}
                \item $K_p = 500$
                \item $T_i = 0.5 \times 0.4 = 0.2 \, \text{s}$
                \item $T_d = 0.125 \times 0.4 = 0.05 \, \text{s}$
            \end{itemize}

            \textbf{Với $700 < k < 1000$:}
            \begin{itemize}
                \item $K_p = 600$
                \item $T_i = 0.5 \times 0.6 = 0.3 \, \text{s}$
                \item $T_d = 0.125 \times 0.6 = 0.075 \, \text{s}$
            \end{itemize}

            \textbf{Với $k > 1000$:}
            \begin{itemize}
                \item $K_p = 700$
                \item $T_i = 0.5 \times 0.8 = 0.4 \, \text{s}$
                \item $T_d = 0.125 \times 0.8 = 0.1 \, \text{s}$
            \end{itemize}

            \subsubsection*{Điều chỉnh tham số PID dựa trên thực nghiệm}

            \hspace*{0.6cm}Trong quá trình vận hành thực tế, các giá trị $T_i$ và $T_d$ tính theo Ziegler--Nichols 
            không hoàn toàn phù hợp với yêu cầu của hệ thống. Vì vậy, các tham số đã được điều chỉnh 
            dựa trên dữ liệu thực nghiệm nhằm đạt được hiệu quả điều khiển tối ưu.

            Các tham số PID cuối cùng được sử dụng như sau:

            \begin{itemize}
                \item Với $k < 700$: \; $K_p = 500$, \; $T_i = 0.1 \, \text{s}$, \; $T_d = 0.2 \, \text{s}$
                \item Với $700 < k < 1000$: \; $K_p = 600$, \; $T_i = 0.3 \, \text{s}$, \; $T_d = 0.01 \, \text{s}$
                \item Với $1000 < k < 1200$: \; $K_p = 700$, \; $T_i = 0.4 \, \text{s}$, \; $T_d = 0.01 \, \text{s}$
            \end{itemize}
    \section{Thiết kế HMI}
        \subsection{Giao diện chính}
            \begin{figure}[H]
                \centering
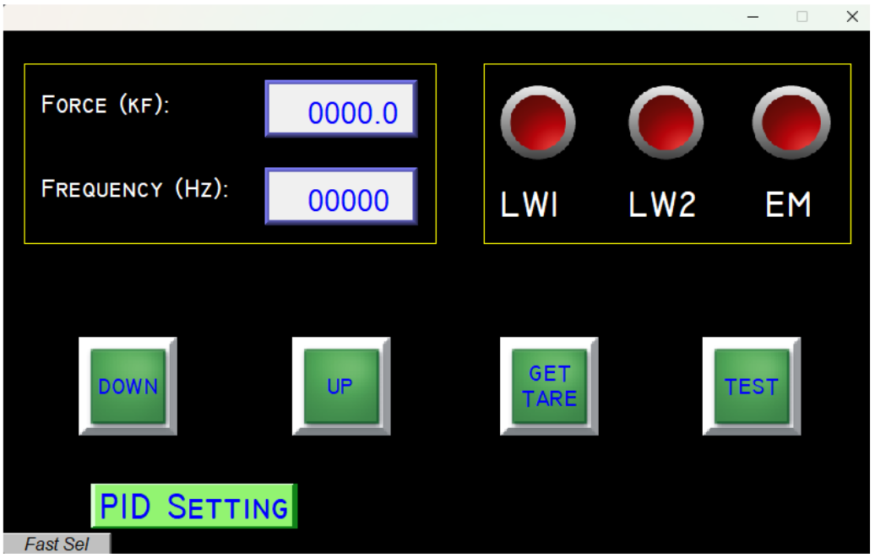
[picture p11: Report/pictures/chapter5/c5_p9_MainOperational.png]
                
                \caption{Giao diện vận hành chính}
                \label{fig:main_interface}
            \end{figure}

            \hspace*{0.6cm}Hình~\ref{fig:main_interface} trình bày giao diện vận hành chính của màn hình HMI. 
            Ở phía bên trái, giao diện hiển thị hai thông số quan trọng: 
            \begin{itemize}
                \item \textbf{Giá trị lực hiện tại}: được đo bởi loadcell và cập nhật theo thời gian thực.
                \item \textbf{Tần số lấy mẫu}: biểu thị tốc độ cập nhật dữ liệu của hệ thống.
            \end{itemize}

            Bảng điều khiển bên phải cho thấy trạng thái của các cảm biến liên quan và bao gồm cả \textbf{nút dừng khẩn cấp (Emergency Stop)} nhằm đảm bảo an toàn trong quá trình vận hành.

            Các nút \textbf{``Up''} và \textbf{``Down''} được dùng để điều khiển thủ công tời nâng, phục vụ cho giai đoạn chuẩn bị như định vị ma nơ canh và căn chỉnh dây an toàn trước khi thử nghiệm.

            Nút \textbf{``Get Tare''} khởi động quy trình đặt giá trị zero cho loadcell, đây là bước bắt buộc cần thực hiện trước khi tiến hành thử. 

            Nút \textbf{``Test''} bắt đầu toàn bộ chu trình thử nghiệm tự động theo thuật toán điều khiển đã lập trình.

            Cuối cùng, nút \textbf{``PID Setting''} cho phép chuyển đến giao diện điều chỉnh các tham số của bộ điều khiển PID, giúp tối ưu hiệu suất điều khiển lực trong quá trình thử.
        \subsection{Giao diện thử nghiệm}
            \begin{figure}[H]
                \centering
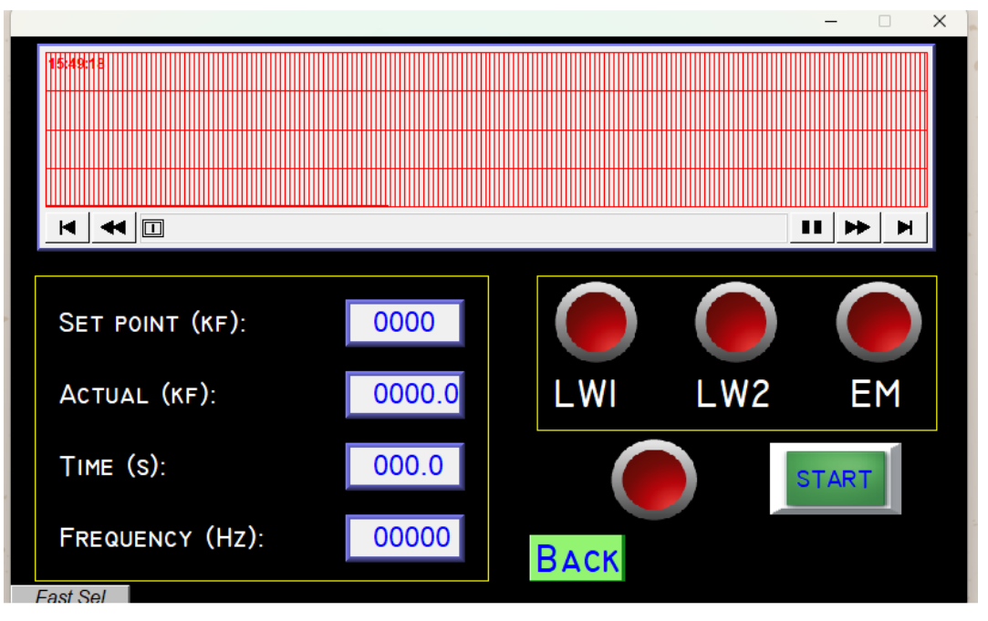
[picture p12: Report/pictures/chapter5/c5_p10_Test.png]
                
                \caption{Giao diện thử nghiệm}
                \label{fig:test_interface}
            \end{figure}
            \hspace*{0.6cm}Hình~\ref{fig:test_interface} minh họa giao diện thử nghiệm của hệ thống. Ở khu vực bên trái,
            các tham số quan trọng được hiển thị theo thời gian thực trong suốt quá trình thử, bao gồm:

            \begin{itemize}
                \item \textbf{Giá trị lực đặt} (setpoint), ví dụ: $15~\mathrm{kN}$,
                \item \textbf{Lực thực tế} đo được từ cảm biến loadcell,
                \item \textbf{Thời gian đã trôi qua} kể từ khi bắt đầu thử nghiệm,
                \item \textbf{Tần số lấy mẫu} hiện tại.
            \end{itemize}

            Khi chu trình thử nghiệm được kích hoạt từ màn hình chính, PLC sẽ thực thi toàn bộ thuật toán
            điều khiển. Kết quả lực đo được sẽ được cập nhật liên tục và biểu diễn dưới dạng đồ thị trong vùng
            hiển thị nằm bên phải giao diện, cho phép người vận hành theo dõi trực quan sự thay đổi của lực
            trong suốt quá trình thử nghiệm.
        \subsection{Giao diện hiệu chỉnh PID}

            \begin{figure}[H]
                \centering
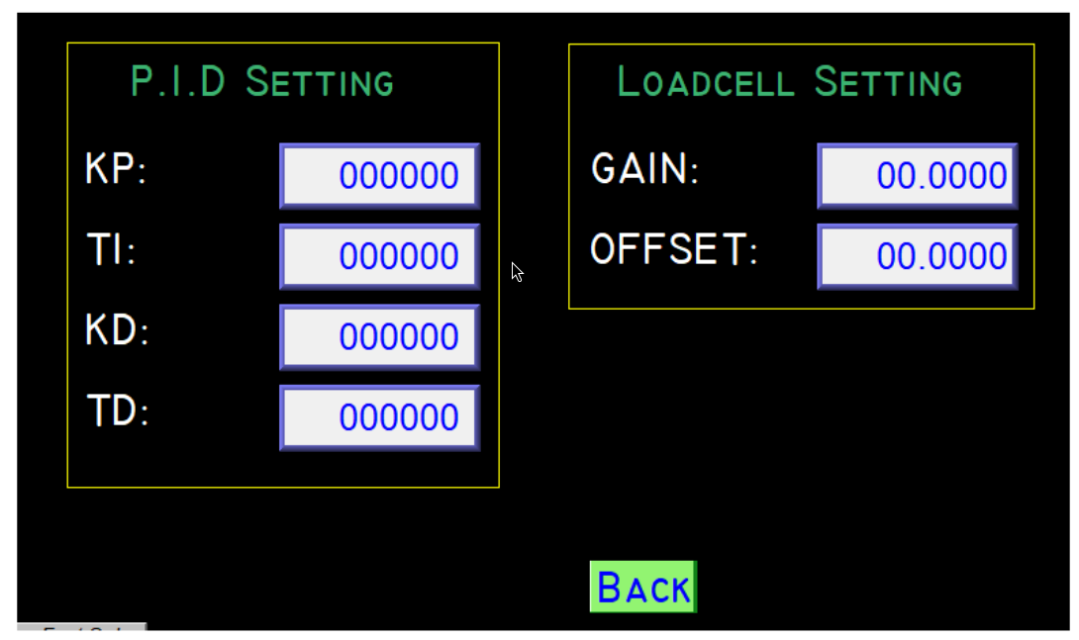
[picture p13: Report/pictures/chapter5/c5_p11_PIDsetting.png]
                
                \caption{Giao diện hiệu chỉnh tham số PID}
                \label{fig:pid_interface}
            \end{figure}

            \hspace*{0.6cm}Giao diện này được chia thành hai phần chính.  
            Phần \textit{PID Setting} cho phép người dùng điều chỉnh các tham số của bộ điều khiển PID.  
            Phần bên phải cung cấp các điều khiển để cài đặt tham số xử lý tín hiệu loadcell, 
            bao gồm hệ số khuếch đại (gain) và giá trị bù (offset) được sử dụng trong quá trình hiệu chuẩn.

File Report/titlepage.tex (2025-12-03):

\begin{titlepage}   
    \begin{center}
        \vspace*{-2cm} 
        \large
        \textbf{ĐẠI HỌC QUỐC GIA THÀNH PHỐ HỒ CHÍ MINH \\
        TRƯỜNG ĐẠI HỌC BÁCH KHOA\\
        KHOA CƠ KHÍ - BỘ MÔN CƠ ĐIỆN TỬ\\}
        \vspace{0.5cm}
         \\
        \rule{\linewidth}{0.5mm}\\
        \vspace{1cm}
        \large
        \textbf{THIẾT KẾ HỆ THỐNG CƠ ĐIỆN TỬ}\\                                                                                                                                                                                                                    
        \vspace*{0.5cm}
        \textbf{ĐỀ TÀI}\\                                                                                                                                                                                                                                                                                                                                                                                                                                             
        \vspace{0.25cm}
        \Large
        \textbf{THIẾT KẾ MÁY KIỂM TRA ĐỘ BỀN TĨNH CỦA DÂY ĐAI AN TOÀN THEO TIÊU CHUẨN TCVN 7802-1:2007}\\
        \vspace{0.5cm}
        \rule{\linewidth}{0.5mm}\\
        \vspace{0.6cm}
        \large
        \textbf{LỚP TN01 - HK 251} \\
        \vspace{0.5cm}
        SINH VIÊN THỰC HIỆN:\\[0.3cm]
        \begin{tabular}{|>{\centering\arraybackslash}m{1cm}|>{\centering\arraybackslash}m{7cm}|>{\centering\arraybackslash}m{5cm}|}
            \hline
            \textbf{STT} & \textbf{Họ và tên} & \textbf{MSSV} \\
            \hline
            1 & Võ Hữu Dư & 2210604 \\
            \hline
            2 & Đào Trọng Chân & 2210350 \\
            \hline
            3 & Dương Quang Duy & 2210497 \\
            \hline
            4 & Trần Quang Đạo & 2210647 \\
            \hline
        \end{tabular}
    \end{center}
        
    \vfill
    \large
    \begin{center}
        TP.HCM, \today
    \end{center}
\end{titlepage}

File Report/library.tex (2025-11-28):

\usepackage{vntex} % Tiếng Việt
\usepackage{graphicx} % Chèn hình ảnh
\usepackage{fancyhdr} % Gói hỗ trợ tạo header và footer fancy
\usepackage{changepage} % Thay đổi lề

% Chèn code
\usepackage{listings} % Thêm gói listings để chèn code
\usepackage{xcolor} % Màu cho code
\lstset{
    language=Python,
    basicstyle=\small\ttfamily,
    numbers=left,
    numberstyle=\tiny\color{gray},
    stepnumber=1,
    numbersep=8pt,
    tabsize=4,
    breaklines=true,
    breakatwhitespace=false,
    xleftmargin=1.5em,
    framexleftmargin=1.5em,
    keywordstyle=\color{blue}\bfseries,
    commentstyle=\color{green!60!black}\itshape,
    stringstyle=\color{orange!80!red},
    identifierstyle=\color{black},
    emphstyle=\color{red},
    frame=single,
    rulecolor=\color{black!30},
    backgroundcolor=\color{gray!5},
    showstringspaces=false,
    captionpos=b,
    morekeywords={True, False, None, self, cv2, np, plt},
    emph={range, len, print, open, str, int, float, list, dict, enumerate, zip},
    emphstyle=\color{purple!80!blue},
}

% Footnote and References
\usepackage[style=numeric,backend=biber]{biblatex} % Sử dụng gói biblatex
\usepackage{capt-of} %  Footnote trong caption
\usepackage[perpage]{footmisc} % Đánh số lại chú thích mỗi trang

% Thiết lập bảng
\usepackage{array} % Gói hỗ trợ các bảng phức tạp
\usepackage{tabularx}
\usepackage{longtable} % Tạo bảng qua nhiều trang
\usepackage{cellspace}
\usepackage{diagbox} % Gói hỗ trợ tạo các ô chéo trong bảng
\usepackage{multirow}
\usepackage{makecell}
\usepackage{xcolor}
\usepackage{colortbl}
\usepackage[export]{adjustbox}

% Thiết lập công thức toán học
\usepackage{amsmath} % Gói hỗ trợ các công thức toán học
\usepackage{amsfonts} % Gói hỗ trợ các ký hiệu toán học
\usepackage{amssymb} % Gói hỗ trợ các ký hiệu toán học
\usepackage{graphicx} % Gói hỗ trợ chèn hình ảnh
\usepackage{bm} % Chữ in đậm trong công thức toán 

% Đồ thị 
\usepackage{pgfplots}
\pgfplotsset{compat=1.18}

% Thiết lập thêm tùy chọn cho dấu gạch đầu dòng
\usepackage{enumitem}

% Thiết lập khác
\usepackage{tikz}
\usepackage{color}
\usepackage{subcaption}
\usepackage{framed}
\usepackage{float} % Để chèn hình ảnh vào đúng vị trí
\usepackage{fancyvrb} % Đưa dữ liệu dạng nguyên thủy vào

% Thiết lập kích thước
\usepackage{geometry}
\geometry{
    left=3cm,
    right=2cm,
    top=2.5cm,
    bottom=2.5cm,
}
\usepackage{hyperref} %Chèn link
\hypersetup{urlcolor=black,linkcolor=black,citecolor=black,colorlinks=true} % Màu cho các đường nét
\everymath{\color{black}}
\pagestyle{fancy}

% Đánh số theo section
\numberwithin{equation}{section}  % Công thức: (1.1), (1.2), (2.1)...
\numberwithin{figure}{section}    % Hình: Figure 1.1, Figure 1.2...
\numberwithin{table}{section}     % Bảng: Table 1.1, Table 1.2...
\AtBeginDocument{%
    \counterwithin{lstlisting}{section}
}

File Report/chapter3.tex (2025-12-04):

\chapter{THIẾT KẾ CƠ KHÍ}
    \section{Yêu cầu thiết kế cơ khí}
        \begin{itemize}
            \item Bảo đảm lực kéo lớn nhất $F_{max} = 15~kN$.
            \item Hành trình thử: $S = 1000~\text{mm}$.
            \item Sơ đồ cơ cấu cơ khí tổng thể được trình bày trên hình dưới đây.
        \end{itemize}
        \begin{figure}[H]
            \centering
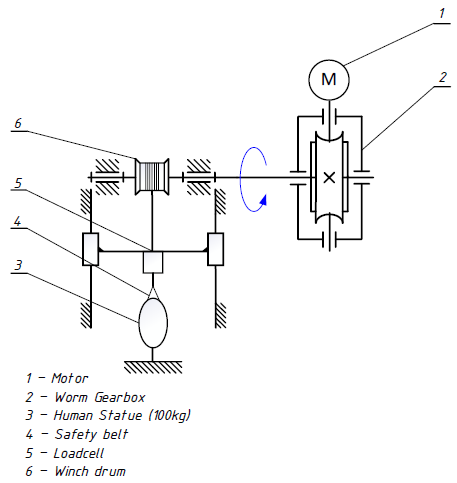
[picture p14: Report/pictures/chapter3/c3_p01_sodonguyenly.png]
            
            \caption{Sơ đồ nguyên lý}
            \label{fig:label}
        \end{figure}
        \hspace*{0.6cm}Các bộ phận chính trên sơ đồ cơ khí:
        \begin{itemize}
            \item Động cơ.
            \item Hộp giảm tốc trục vít.
            \item Mô hình người $(100~\text{kg})$.
            \item Dây đai an toàn.
            \item Cảm biến lực (loadcell).
            \item Tời kéo.
        \end{itemize}

    \section{Tính toán thiết kế}
        \subsection{Tính toán lựa chọn tời kéo}

            \hspace*{0.6cm}\textbf{Lựa chọn tời kéo:}\\[0.2cm]
            \hspace*{0.6cm}Theo thông tin từ các nhà sản xuất tời điện như Emcé Winches và Thern Winches, lực kéo danh nghĩa tối thiểu của tời chọn phải lớn hơn $1,3 \div 1,5$ lần tải trọng cần kéo để bảo đảm an toàn và hiệu quả làm việc.

            Với yêu cầu lực kéo của cáp tương đương tải trọng 1500 kg, cần chọn tời có sức kéo trong khoảng $1950 \div 2250$ kg.

            Để phù hợp với các cấp tải chuẩn dạng có trên thị trường, chọn tời có sức kéo danh nghĩa 2000 kg (2 tấn).

            Khả năng tải của tời thay đổi theo số lớp cáp quấn trên tang. Khi cáp gần như được tháo hết và chỉ còn một lớp trên tang tới thì tời đạt khả năng tải lớn nhất, gọi là \textit{tải lớp thứ nhất}. Khi số lớp cáp quấn tăng dần cho đến khi đầy tang, khả năng tải giảm xuống, gọi là \textit{tải khi quấn đầy}. Do đó, đối với máy thử, chỉ cần quấn một lớp cáp là đã đủ cho hành trình thử và đồng thời bảo đảm khả năng tải của tời.\\

            \textbf{Lựa chọn hộp giảm tốc:}\\[0.2cm]
            \hspace*{0.6cm}Với yêu cầu kéo của tời nêu trong phần thông số thiết kế, hộp giảm tốc trục vít là lựa chọn tối ưu vì:
            \begin{itemize}
                \item Có khả năng tự hãm tốt, phù hợp với bài toán kéo thẳng đứng, cho phép giữ tải mà không cần hệ thống phanh bổ sung.
                \item Tạo mômen xoắn lớn, không cần chọn động cơ công suất quá lớn, giúp tiết kiệm chi phí và không gian bố trí trên thân máy phía trên.
            \end{itemize}

            \textbf{Lựa chọn hệ tời kéo:}\\[0.2cm]
            \hspace*{0.6cm}Lực kéo yêu cầu: $F = 15000$ N.

            Để thuận tiện cho việc tính toán, trước tiên lựa chọn sơ bộ một bộ tời nhằm xác định đường kính tang phục vụ tính công suất. Như đã phân tích ở trên, chọn một tời điện có sức kéo tối thiểu 2 tấn, sử dụng hộp giảm tốc trục vít.

            Do đó, lựa chọn sơ bộ tời thuộc series 3WG4 Atlas II -- Worm Gear của hãng Thern Winches, với đường kính tang $D = 102$ mm.

            Bán kính tang: $r = 51$ mm $= 0.051$ m.

            Mômen xoắn trên trục tang:
            \begin{equation}
                T = F \times r = 20000 \times 0.051 = 1020~N.m = 1020~000~N.mm.
            \end{equation}

            Với hành trình thử $S = 1000$ mm (1 m) trong thời gian $t = 240$ s, vận tốc nâng là:
            \begin{equation}
                V = \frac{S}{t} = \frac{1}{240} = 0.0042~m/s.
            \end{equation}

            Chu vi tang:
            \begin{equation}
                C = \pi \times D = \pi \times 102 \approx 320.44~mm \approx 0.3204~m.
            \end{equation}

            Tốc độ quay của tang tời:
            \begin{equation}
                n = \frac{v}{C} \times 60 = \frac{0.0042}{0.3204} \times 6 \approx 0.8~\text{vòng/phút}~(RPM).
            \end{equation}

            Công suất cần thiết để kéo tải:
            \begin{equation}
                P_{ct} = \frac{T \times n}{9.55 \times 10^6} \approx 0.1~kW.
            \end{equation}

            Như vậy, để đáp ứng yêu cầu thiết kế, hệ thống phải thỏa mãn:
            \begin{equation}
                P_{winch} \geq P_{ct}
            \end{equation}

            \begin{equation}
                V_{winch} \geq V
            \end{equation}

            Dựa vào các tiêu chí trên, tời 3WG4 Atlas II Worm Gear được lựa chọn vì đáp ứng yêu cầu thiết kế.

            \begin{table}[H]
                \centering
                \caption{Thông số kỹ thuật tời kéo}
                \begin{tabular}{|l|c|c|}
                    \hline
                    \textbf{Thông số} & \textbf{Đơn vị} & \textbf{Giá trị} \\
                    \hline
                    Mã nhà sản xuất & & 3WG4-B4600-9S6 \\
                    \hline
                    Công suất động cơ & kW & 1,4 \\
                    \hline
                    Thời gian làm việc định mức & phút & 15 \\
                    \hline
                    Tải trọng lớp cáp thứ nhất & kg & 2086 \\
                    \hline
                    Tốc độ tang lớp cáp thứ nhất & vòng/phút & 8,6 \\
                    \hline
                    Điện áp nguồn & V, pha & 220 V, 3 pha \\
                    \hline
                    Dung lượng tang lớp cáp thứ nhất & m & 5,4 \\
                    \hline
                    Đường kính tang & mm & 102 \\
                    \hline
                    Khối lượng tời & kg & 111 \\
                    \hline
                    Tốc độ quay động cơ & vòng/phút & 1725 \\
                    \hline
                    Tỷ số truyền hộp giảm tốc trục vít cấp 1 & & 7,5:1 \\
                    \hline
                    Tỷ số truyền hộp giảm tốc trục vít cấp 2 & & 20:1 \\
                    \hline
                \end{tabular}
                \label{tab:winch_specs}
            \end{table}

            \begin{figure}[H]
                \centering
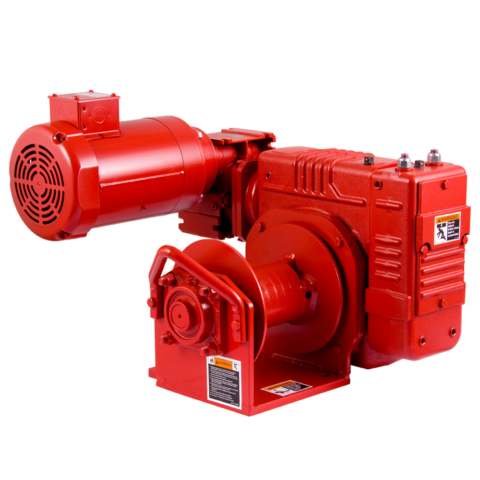
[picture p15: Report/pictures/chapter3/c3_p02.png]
                
                \caption{Tời kéo dòng 3WG4}
                \label{fig:winch_3wg4}
            \end{figure}

        \subsection{Tính toán lựa chọn cốt và bạc trượt dẫn hướng}

            \hspace*{0.6cm}Để dẫn hướng dầm ngang khi tác dụng lực kéo, cần bố sung các cốt dẫn hướng và cụm bạc trượt. Hãi dạng dẫn hướng phổ biến là ray dẫn hướng tiết diện chữ nhật và trục tròn. Đối với trục tròn còn có biến thể trục spline với các rãnh bi trên trục, kết hợp bạc bi trượt, giúp giảm ma sát khi chuyển động.

            Dạng ray chữ nhật có ưu cùng ưỡn độc trực tốt hơn dạng trục tròn (bao gồm cả trục spline). Tuy nhiên, ray chữ nhật có chi phí, tính phổ biến và dễ chế tạo lắp ráp, phương án sử dụng trục tròn trơn kết hợp bạc trượt bi tuyến tính được chọn làm cốt dẫn hướng và cụm đỡ.

            Hệ thống sử dụng 4 bạc trượt tuyến tính dạng LMK lắp trên 2 trục dẫn hướng, loadcell được đặt giữa hai trục. Cấu trúc này bảo đảm khả năng dẫn hướng chính xác trong quá trình làm việc của thiết bị. Lực kéo chính tử hệ tời khổng tác dụng trực tiếp lên bạc trượt mà truyền qua thanh biên kết vă loadcell. Các bạc đỡ cốt chỉ yêu cầu tải trong đó trong hường cụm dẫn hướng, bao gồm trọng lượng hai trục dẫn hướng, cụm kết câu liên kết với loadcell và các chi tiết khác gắn trên cụm dẫn hướng.

            Do sử dụng 4 bạc trượt nên tải trọng được chia đều cho từng bạc.

            Xác định tải trọng tác dụng lên mỗi bạc trượt tuyến tính:

            Theo thiết kế, tổng trọng lượng cụm dẫn hướng xấp xỉ 50 kg (tương đương khoảng 490 N). Mỗi trục dẫn hướng chịu 25 kg ($\approx$ 245 N). Mỗi trục có 2 bạc trượt nên tải trên mỗi bạc:

            \begin{equation}
                F_{bạc} \approx 245~N.
            \end{equation}

            Xét hệ số an toàn $n = 2$ (do có thể xảy ra rung động lớn khi dây đai bị đứt trong quá trình kéo), mỗi bạc trượt cần chịu được tải trọng cực đại xấp xỉ 245 N (dã kể đến hệ số an toàn bạc).

            Phân tích và tính toán tải trọng tác dụng lên trục dẫn hướng:

            Trong trạng thái làm việc, trục dẫn hướng bố trí theo phương thẳng đứng, tải trọng chính tác dụng lên trục là lực nén đọc trục. Ngoài ra còn có thành phần uốn do trọng lượng các chi tiết gắn trên trục. Khi thiết kế, cần kiểm tra động thời đều kiện bền nén và độ cứng (độ võng) của trục.

            Độ võng ngang lớn nhất của một trục dặt thẳng đứng, ngàm chặt hai đầu, chịu tải tập trung ở giữa:

            \begin{equation}
                \delta = \frac{FL^3}{192EI}
            \end{equation}

            Trong đó:

            \begin{itemize}
                \item $\delta = 1$ mm là độ võng ngang cho phép tại giữa trục;
                \item $F = 245 \times 2 = 490$ N là lực tác dụng lên mỗi trục (N);
                \item $L = 2$ m là chiều dài trục;
                \item $E = 2,1 \times 10^{11}~N/m^2$ là môđun đàn hồi đọc (Young) của vật liệu thép;
                \item I là mômen quán tính tiết diện $(mm^4)$.
            \end{itemize}

            Với trục tròn đặc, mômen quán tính tiết diện:

            \begin{equation}
                I = \frac{\pi d^4}{64}
            \end{equation}

            Suy ra đường kính cần thiết của trục:

            \begin{equation}
                d \geq \sqrt[4]{\frac{64I}{\pi}} = \sqrt[4]{64 \times \frac{7}{72000000\pi}} \approx 0.0375~mm \approx 37,5~mm.
            \end{equation}

            Kết quả cho thấy đường kính tối thiểu của trục vào khoảng 37,5 mm để bảo đảm độ võng của trục không vượt quá 1 mm. Để tăng độ cứng và bảo đảm an toàn khi vận hành, chọn trục có đường kính tiêu chuẩn $d = 40$ mm.

            Theo các kích thước tiêu chuẩn, chọn trục tròn đặc đường kính 40 mm, chiều dài 2000 mm. Bạc trượt sử dụng loại LMK40UU của hãng THK (thông số chi tiết xem Bảng 5).

            \begin{table}[H]
                \centering
                \caption{Thông số kỹ thuật bạc trượt LMK40UU}
                \begin{tabular}{|l|c|c|}
                    \hline
                    \textbf{Thông số} & \textbf{Đơn vị} & \textbf{Giá trị} \\
                    \hline
                    Mã sản phẩm & & LMK40UU \\
                    \hline
                    Tải trọng động cho phép & N & 2160 \\
                    \hline
                    Tải trọng tĩnh cho phép $C_0$ & N & 4020 \\
                    \hline
                    Khối lượng & g & 864 \\
                    \hline
                    Đường kính trục (Dr) & mm & 40 \\
                    \hline
                    Dung sai Dr & mm & $0/-0,012$ \\
                    \hline
                    Đường kính ngoài (D) & mm & 37 \\
                    \hline
                    Dung sai D & mm & $0/-0,019$ \\
                    \hline
                    Chiều dài bạc (L) & mm & 80 \\
                    \hline
                    Dung sai L & $\mu$m & $0/-300$ \\
                    \hline
                    Kích thước mặt bích (Df) & mm & 96 \\
                    \hline
                    Khoảng cách lỗ bu lông (K) & mm & 75 \\
                    \hline
                    Chiều dày mặt bích (T) & mm & 13 \\
                    \hline
                    Đường kính vòng lỗ bu lông (Dp) & mm & 78 \\
                    \hline
                    Kích thước X & mm & 9 \\
                    \hline
                    Kích thước Y & mm & 14 \\
                    \hline
                    Kích thước Z & mm & 8,6 \\
                    \hline
                    Độ lệch tâm cho phép & $\mu$m & 20 \\
                    \hline
                    Độ vuông góc cho phép & $\mu$m & 20 \\
                    \hline
                \end{tabular}
                \label{tab:lmk40uu_specs}
            \end{table}
            \begin{figure}[H]
                \centering
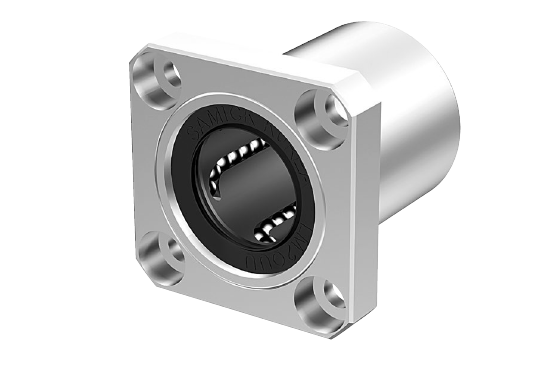
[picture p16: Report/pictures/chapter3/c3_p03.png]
                
                \caption{LMK40UU}
                \label{fig:lmk40uu}
            \end{figure}

        \subsection{Tính toán bu lông lắp loadcell}

            \hspace*{0.6cm}Trong kết cấu, loadcell được lắp bằng một bu lông chịu kéo. Bu lông được siết chặt và làm việc trong điều kiện lực đọc trục biến thiên, có khe hở. Để đơn giản, có thể coi bu lông chịu lực kéo đọc trục không đổi bằng lực kéo cực đại $F_b$ có kể đến hệ số an toàn.

            Theo mục 17.5.4 (tr. 585) của [1], lực siết ban đầu (lực tiền siết) của bu lông được xác định:

            \begin{equation}
                V = \frac{k \cdot F}{i \cdot f} \approx 10 F
            \end{equation}

            Trong đó:

            \begin{itemize}
                \item $V$ -- lực tiền siết của bu lông (N);
                \item $k$ -- hệ số an toàn, thường chọn $1,3 \div 1,5$;
                \item $F$ -- lực đọc trục tác dụng lên bu lông (N);
                \item $i$ -- số bề mặt tiếp xúc giữa các tấm ghép;
                \item $f$ -- hệ số ma sát $(0,15 \div 0,2$ đối với bề mặt thép và gang).
            \end{itemize}

            Tuy nhiên, trong kết cấu này bu lông chỉ có nhiệm vụ chịu lực kéo, không dùng để ghép chặt nhiều tấm, nên có thể bỏ qua lực tiền siết V.

            Tổng lực tác dụng lên bu lông sau khi chịu tải:

            \begin{equation}
                F_{\Sigma} = V + \chi F
            \end{equation}

            Trong đó:

            \begin{itemize}
                \item $F_{\Sigma}$ -- tổng lực tác dụng lên bu lông sau khi có tải đọc trục (N);
                \item $V$ -- lực tiền siết bu lông (N);
                \item $\chi$ -- hệ số phân bổ ngoại lực $(0,2 \div 0,3$ với tấm thép/gang và bu lông thép);
                \item $F$ -- lực đọc trục tác dụng lên tấm (N).
            \end{itemize}

            Vì lực kéo tác dụng trực tiếp lên bu lông nên tổng lực bằng đúng lực kéo cực đại:

            \begin{equation}
                F_g = F_b = 20000~N.
            \end{equation}

            Ứng suất kéo trong thân bu lông:

            \begin{equation}
                \sigma_k = \frac{4 F_{\Sigma}}{\pi d_1^2} \leq [\sigma_k]
            \end{equation}

            Trong đó:

            \begin{itemize}
                \item $\sigma_k$ -- ứng suất kéo trong thân bu lông (MPa);
                \item $d_1$ -- đường kính chân ren (mm);
                \item $[\sigma_k]$ -- ứng suất kéo cho phép của vật liệu (MPa).
            \end{itemize}

            Suy ra đường kính chân ren cần thiết:

            \begin{equation}
                d_1 \geq \sqrt{\frac{4F_{\Sigma}}{\pi [\sigma_k]}}
            \end{equation}

            Với lực đọc trục cực đại bằng lực kéo $F_b = 20000~N$, sử dụng bu lông và tấm ghép bằng thép, chọn vật liệu bu lông cấp bền 8.8 (bu lông đen). Ứng suất chảy của vật liệu:

            \begin{equation}
                \sigma_{ch} = 640~MPa.
            \end{equation}

            Theo công thức (3.26) [1], ứng suất kéo cho phép:

            \begin{equation}
                [\sigma_k] = \frac{\sigma_{ch}}{[s]}
            \end{equation}

            Trong đó:

            \begin{itemize}
                \item $\sigma_{ch}$ -- ứng suất chảy của vật liệu bu lông (MPa) (tham khảo Bảng 17.4, tr. 575);
                \item $s$ -- hệ số an toàn (tham khảo Bảng 17.6, tr. 577).
            \end{itemize}

            Với $\sigma_{ch} = 640~MPa$ và chọn [s] = 10 (bu lông M6--M16, thép cácbon, chịu tải thay đổi):

            \begin{equation}
                [\sigma_k] = \frac{640}{10} = 64~MPa.
            \end{equation}

            Từ (10):

            \begin{equation}
                d_1 = \sqrt{\frac{4 \times 20000}{\pi \times 64}} \approx 19,95~mm.
            \end{equation}

            Tra Bảng 17.7 (tr. 581) các cỡ bu lông thông dụng, đường kính chân ren $d_1 \approx 19,95~mm$ tương ứng với bu lông M20.

            \textbf{Kết luận:} Chọn bu lông M20, cấp bền 8.8, bu lông đen bằng thép cácbon để lắp loadcell giữa hai dầm ngang.

        \subsection{Tính toán bu lông treo móc}
            \begin{figure}[H]
                \centering
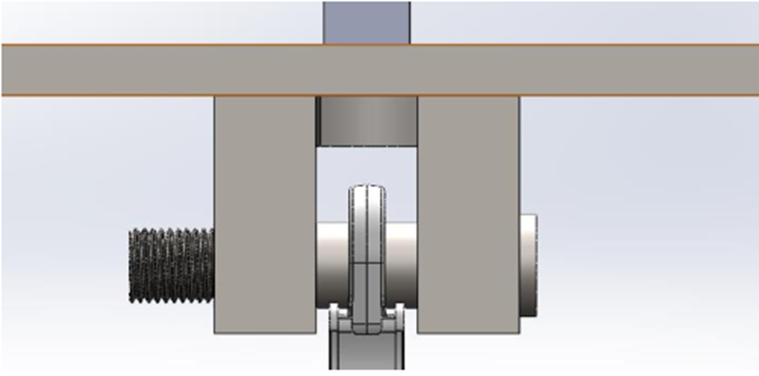
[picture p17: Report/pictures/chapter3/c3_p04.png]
                
                \caption{Tính toán bu lông treo móc}
                \label{fig:bolt_hook}
            \end{figure}
            \hspace*{0.6cm}Kết cấu sử dụng một bu lông duy nhất để bắt mốc vào dầm ngang, vì vậy bu lông này phải chịu toàn bộ tải thử 20 kN. Để đảm bảo độ bền của chốt bu lông, ta mô hình hóa phần thân bu lông làm việc giống như một trục tròn chịu uốn, do vùng tiếp xúc giữa bu lông và hai chi tiết kẹp có thể coi như một đoạn trục. Cách tiếp cận này xem bu lông như một dầm giản đơn có nhịp L chịu lực tập trung ở giữa $F = 20$ kN, sinh ra ứng suất cắt và ứng suất uốn trong bu lông.
            \begin{figure}[H]
                \centering
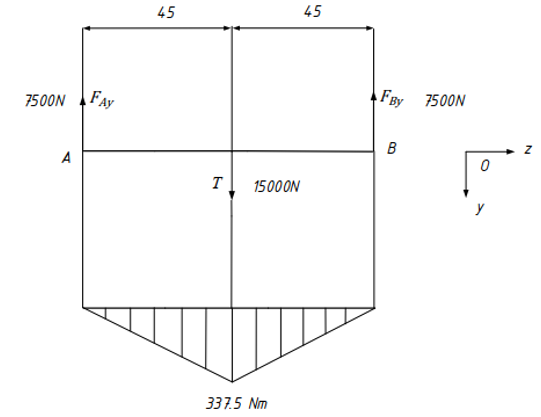
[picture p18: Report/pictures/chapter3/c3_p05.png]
                
                \caption{Biểu đồ momen uốn và lực cắt trên bu lông}
                \label{fig:bolt_hook}
            \end{figure}

            Từ điều kiện bền theo uốn (ứng suất tương đương không được vượt quá $[\sigma]$), đường kính tối thiểu của bu lông được xác định theo biểu thức:

            \begin{equation}
                d_{bolt} \geq 10 \cdot \sqrt[3]{\frac{M_b}{0,1 [\sigma]}} \geq 23,21~mm
            \end{equation}

            Trong đó $[\sigma]$ là giới hạn chảy nhỏ nhất của thép C45 theo tiêu chuẩn ASTM, $[\sigma] = 360$ MPa. Để thuận tiện cho chế tạo, ta chọn $d_{bolt} = 25~mm$.

            \textbf{Kiểm nghiệm bền tĩnh của bu lông}

            Vì bu lông không quay nên chỉ cần kiểm tra bền tĩnh.

            \begin{equation}
                W = 0,1 \cdot d^3 = 0,1 \cdot 25^3 = 1562,5~mm^3
            \end{equation}

            \begin{equation}
                W_0 = 0,2 \cdot d^3 = 0,2 \cdot 25^3 = 3125~mm^3
            \end{equation}

            Ứng suất tương đương theo thuyết năng lượng biến dạng (von Mises) được tính:

            \begin{equation}
                \sigma_{td} = \sqrt{\sigma^2 + 3\tau^2} \leq [\sigma]
            \end{equation}

            Với $[\sigma] = 250~MPa$, $\sigma = \frac{M}{W}$ và $\tau = 0$ (bu lông không chịu xoắn), ta có:

            \begin{equation}
                \sigma_{td} = \frac{337500}{1562,5} = 216~MPa \leq 360~MPa
            \end{equation}

            Như vậy, bu lông thỏa điều kiện bền tĩnh và an toàn khi sử dụng.

            Mô phỏng kiểm nghiệm trên SolidWorks cho cụm gối đỡ trục và trục được trình bày ở các hình sau.

            \begin{figure}[H]
                \centering
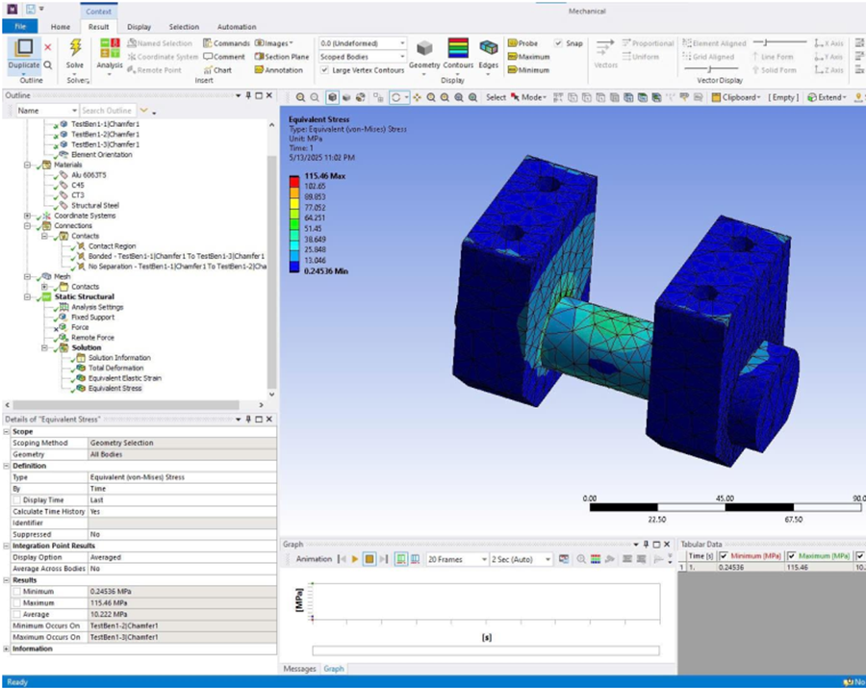
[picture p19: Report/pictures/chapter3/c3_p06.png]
                
                \caption{Kiểm tra ứng xuất trên gá đỡ trục}
                \label{fig:stress_bracket}
            \end{figure}

        \subsection{Thiết kế khung máy}

            \hspace*{0.6cm}Khung máy sử dụng nhôm định hình HFSF8-4080 của Misumi Việt Nam làm vật liệu chính.

            Lựa chọn nhôm định hình mang lại nhiều ưu điểm thực tế cho thiết kế. Thứ nhất, nhôm định hình có khối lượng nhẹ nhưng vẫn đảm bảo độ bền cao, giúp giảm tổng khối lượng máy mà không làm suy giảm độ cứng, phù hợp với yêu cầu kỹ thuật của hệ thống. Thứ hai, kết cấu rãnh T của nhôm định hình cho phép lắp ráp linh hoạt, dễ dàng điều chỉnh vị trí các chi tiết mà không cần hàn hay gia công phức tạp, qua đó tiết kiệm đáng kể thời gian và chi phí chế tạo. Ngoài ra, lớp ô-xít tự nhiên trên bề mặt nhôm giúp tăng khả năng chống ăn mòn, đảm bảo tuổi thọ khung trong môi trường phòng thí nghiệm và giảm nhu cầu bảo trì.

    \section{Kiểm nghiệm độ bền khung máy}

        \hspace*{0.6cm}Do tải trọng làm việc của máy tương đối lớn (tới 2 tấn), để đảm bảo an toàn cho người sử dụng và khả năng làm việc lâu dài, cần tiến hành kiểm nghiệm sức bền cho khung máy. Bên cạnh đó, khung sử dụng nhôm định hình làm kết cấu chính và có chiều cao tổng thể khoảng 2000 mm (2 m), là chiều dài tương đối lớn nên có nguy cơ xuất hiện hiện tượng oán (mất ổn định uốn).

        \begin{figure}[H]
            \centering
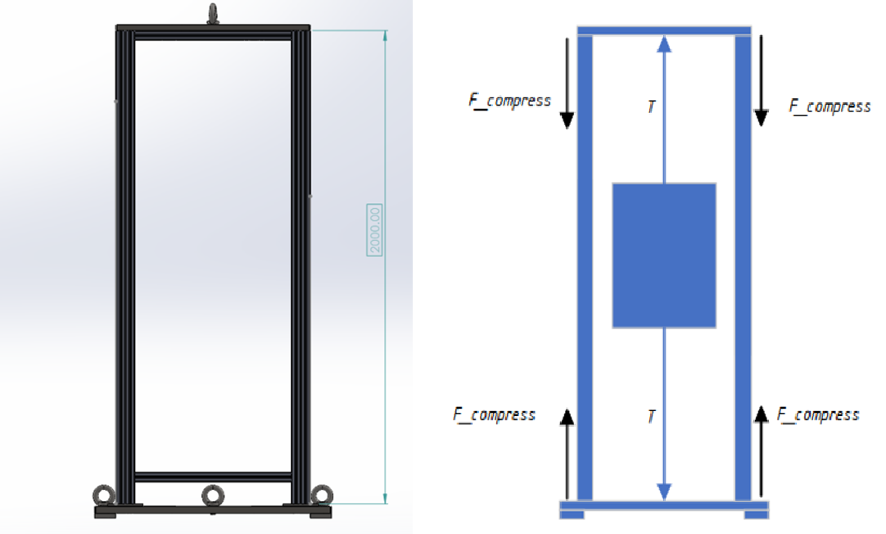
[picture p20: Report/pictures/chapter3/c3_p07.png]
            
            \caption{Khung nhôm}
            \label{fig:aluminum_frame}
        \end{figure}

        Hiện tượng oán xuất hiện khi thanh chịu nén tới một giá trị tải trọng nhất định làm thay đổi hình dạng ban đầu của thanh. Biến dạng cong này ban đầu có thể nhỏ, nhưng về lâu dài sẽ gây ảnh số và có thể dần tới hư hỏng nghiêm trọng cho máy.

        Trước hết, cần xác định cột có được xem là thanh mảnh hay không, vì công thức Euler chỉ áp dụng cho trường hợp thanh bị oán dẻo hỏi (ứng suất trong thanh tại thời điểm oán nhỏ hơn giới hạn chảy của vật liệu). Nếu thanh ngắn (thanh thường xây ra với các thanh dài, mảnh. Với các thanh ngắn hoặc trung bình, hiện tượng oán xảy ra trong vùng dẻo (ứng suất vượt giới hạn tỉ lệ), và khi đó dùng trực tiếp công thức Euler sẽ cho kết quả không an toàn (tải trọng tới hạn tính được cao hơn thực tế).

        Tỷ số độ mảnh $\lambda$ là thám số chính dùng để phân loại thanh (ngắn, trung bình hay dài) và quyết định có áp dụng công thức Euler hay không:

        \begin{equation}
            \lambda = \frac{l_z}{r_{min}}
        \end{equation}

        Trong đó bán kính quán tính nhỏ nhất $r_{min}$ được xác định bởi:

        \begin{equation}
            r_{min} = \sqrt{\frac{I_{min}}{A}}
        \end{equation}

        Với $I_{min}$ và $A$ là mô men quán tính nhỏ nhất và diện tích tiết diện ngang, tra theo catalogue của Misumi.

        Từ dữ liệu nhà sản xuất: $r_{min} \approx 0.01336$ m.

        \begin{equation}
            \lambda = \frac{l_z}{r_{min}} = \frac{1}{0.01336} \approx 74.85
        \end{equation}

        Tỷ số độ mảnh tới hạn của nhôm 6061 được cho bởi:

        \begin{equation}
            \lambda_c = \pi \cdot \sqrt{\frac{E}{\sigma_y}} = 49.6
        \end{equation}

        Trong đó $\sigma_y$ là giới hạn chảy của nhôm 6061. Vì $\lambda > \lambda_c$ nên cột được xem là thanh dài (slender column), do đó việc sử dụng công thức Euler để tính tải trọng tới hạn là phù hợp.

        Để tính tải trọng tới hạn của cột, sử dụng công thức Euler:

        \begin{equation}
            P_{cr} = \frac{\pi^2 \cdot E \cdot I}{L_e^2}
        \end{equation}

        Trong đó:

        \begin{itemize}
            \item E: mô đun đàn hồi của nhôm 6061, $E = 68~GPa$.
            \item I: mô men quán tính tiết diện, $I = 19.8 \times 10^{-8}~m^4$.
            \item $L_e$: chiều dài tính toán của cột. Với hai đầu cột được cố định, ta có $L_e = 0.5 \cdot L = 1$ m.
        \end{itemize}

        Từ (21) suy ra tải trọng tới hạn trước khi oán của cột:

        \begin{equation}
            P_{cr} \approx 132884~N
        \end{equation}

        Hệ số an toàn đối với mất ổn định được tính:

        \begin{equation}
            FOS = \frac{P_{cr}}{F_{load}} = \frac{132884}{20000} \approx 6.64
        \end{equation}

        Giá trị $FOS \approx 6.64 > 1$ khá lớn, cho thấy khả năng oán tổng thể của khung theo tính toán lý thuyết là thấp. Tuy nhiên, để kiểm chứng kết quả và đánh giá phân bố ứng suất, biến dạng trên toàn bộ kết cấu, ta tiến hành mô phỏng phần tử hữu hạn (FEA) trên SolidWorks.

        \begin{figure}[H]
            \centering
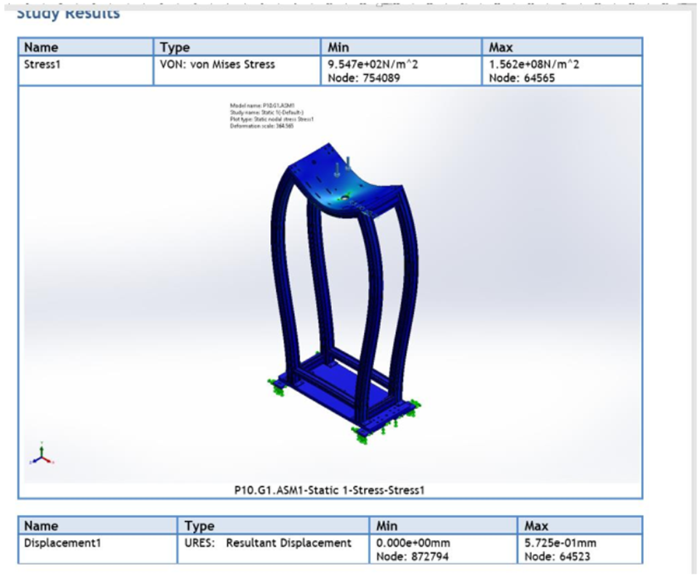
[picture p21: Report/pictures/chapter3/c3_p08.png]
            
            \caption{Thử nghiệm ứng suất trên kết cấu}
            \label{fig:stress_test_frame}
        \end{figure}

        Kết quả mô phỏng cho thấy ứng suất von Mises lớn nhất trong khung vào khoảng $1,562 \times 10^8~N/m^2$, vẫn thấp hơn giới hạn chảy của nhôm 6061 nên kết cấu đảm bảo điều kiện bền về ứng suất.

        \begin{figure}[H]
            \centering
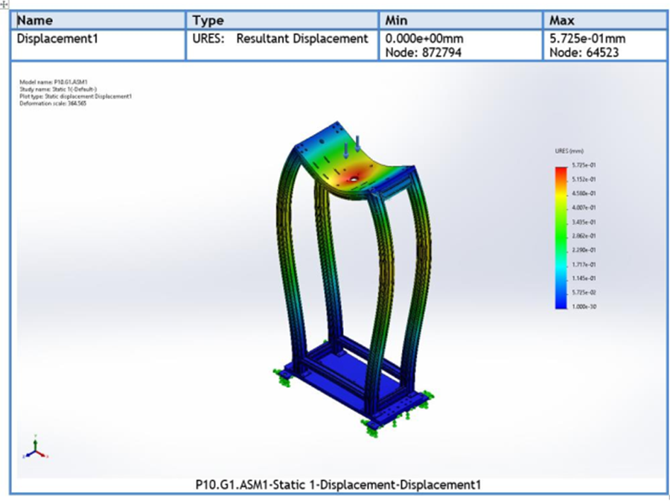
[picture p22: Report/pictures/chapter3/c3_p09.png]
            
            \caption{Kiểm nghiệm chuyển vị của kết cấu}
            \label{fig:displacement_test_frame}
        \end{figure}

        Hình dạng biến dạng và tháng màu cho thấy chuyển vị tổng hợp lớn nhất của kết cấu vào khoảng $URES_{max} \approx 5,675 \times 10^{-3}~mm$, xấp xỉ 0,6 mm. Chuyển vị lớn nhất tập trung chủ yếu tại vùng giữa của dầm ngang phía trên -- đây là vị trí chịu lực trực tiếp từ tải trọng dùng, kết quả này hợp lý về mặt cơ học.

        Tuy nhiên, quan sát hình dạng biến dạng cũng cho thấy hai cột đứng chính của khung có xu hướng cong ra ngoài, đặc biệt ở vùng giữa chiều cao. Mặc dù giá trị chuyển vị ngang tại đây không phải là nhất toán kết cấu, nhưng dạng cong này phản ánh có xu hướng mất ổn định (oán) cục bộ của cột. Nguyên nhân là do các cột khá mảnh và trọng cẩu hình ban đầu gần như không có giằng ngang ở giữa chiều cao, nên dễ bị mất ổn định khi chịu nén đọc trục.

        Giá trị chuyển vị ngang tại cột vào khoảng $0,2 - 0,3$ mm, không quá lớn, nhưng để tăng độ an toàn và độ cứng tổng thể, ta tiến hành gia cường bằng các thanh giằng ngang.

        Để tăng độ an toàn và độ cứng tổng thể, ta tiến hành gia cường bằng các thanh giằng ngang. Việc thêm một thanh giằng ngang làm giảm đáng kể độ dài tự do của cột, từ đó hạn chế xu hướng oán và giảm mức độ võng của khung. Ngoài ra, chuyển vị các cột thẳng đứng và giảm một phần áp dịch chuyển của tấm thép trên cùng.

        \begin{figure}[H]
            \centering
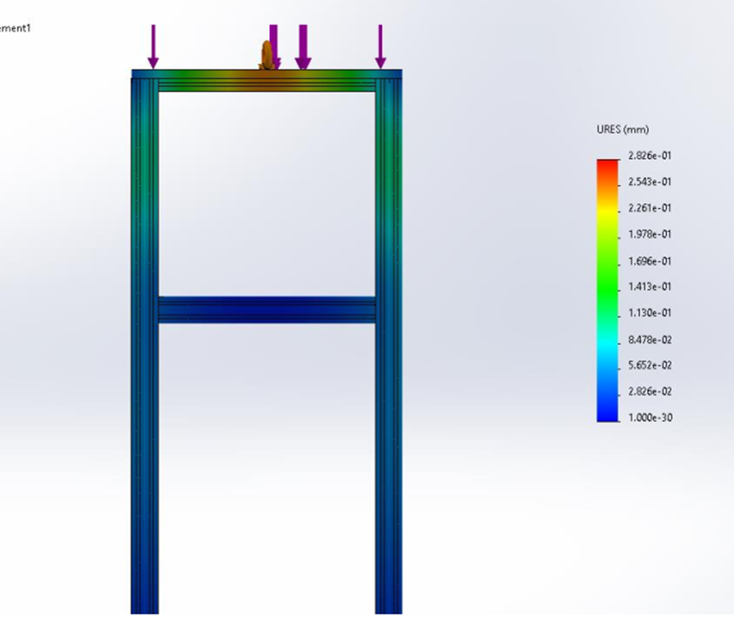
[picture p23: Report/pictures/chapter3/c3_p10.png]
            
            \caption{Kiểm nghiệm chuyển vị của kết cấu sau khi thêm một thanh ngang}
            \label{fig:displacement_after_brace}
        \end{figure}

        Sau khi bổ sung một thanh giằng ngang tại vị trí giữa hai cột, chuyển vị của các cột giảm đáng kể, đồng thời chuyển vị tại bản thép phía trên cũng giảm một phần.

        Tiếp tục bổ sung thêm một thanh giằng ngang thứ hai tại vị trí tối hạn, kết quả mô phỏng cho thấy chuyển vị lớn nhất trên bản thép phía trên giảm xuống còn khoảng 0,22 mm, trong khi chuyển vị tại cột chỉ khoảng 0,06 mm. Các giá trị này rất nhỏ, đảm bảo rằng biến dạng kết cấu không gây ảnh số đáng kể trong quá trình làm việc.
        \begin{figure}[H]
            \centering
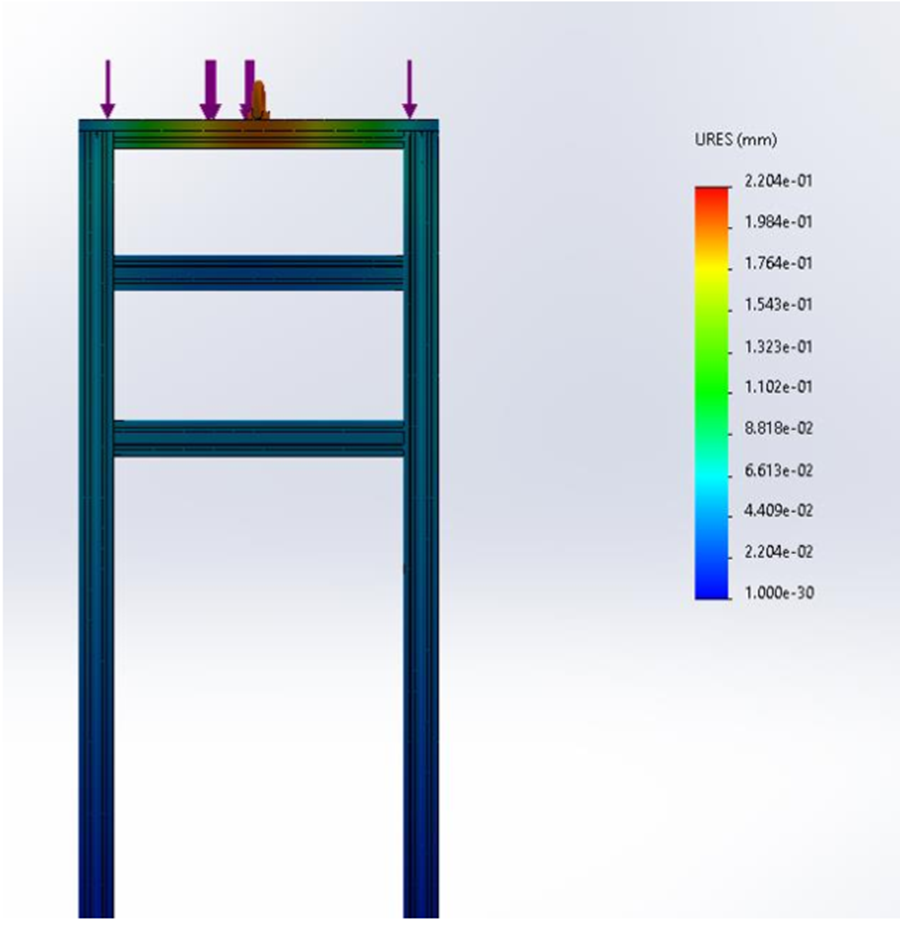
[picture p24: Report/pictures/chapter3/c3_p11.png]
            
            \caption{Kiểm nghiệm chuyển vị của kết cấu sau khi thêm hai thanh ngang}
            \label{fig:displacement_two_braces}
        \end{figure}

        Về mặt lý thuyết, có thể giảm nguy cơ oán bằng cách giảm chiều dài cột. Tuy nhiên, trong bài toán này, việc giảm chiều cao khung để hạn chế hiện tượng oán là không hợp lý, vì sẽ làm giảm hành trình làm việc của máy, gây khó khăn cho vận hành. Đồng thời, yêu cầu máy phải đạt lực tối hạn trong một khoảng thời gian nhất định, và việc giảm chiều cao sẽ buộc tời phải kéo với tốc độ rất nhỏ, làm việc điều khiển trở nên phức tạp hơn.

        Do đó, phương án tối ưu được lựa chọn là giữ nguyên chiều cao khung, đồng thời bổ sung các giằng ngang tại vị trí thích hợp để tăng độ cứng và nâng cao hệ số an toàn chống oằn.

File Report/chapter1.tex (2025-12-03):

\chapter{TỔNG QUAN}
    
    \section{Lý do chọn đề tài và các khái niệm chính}
        \subsection{Lý do chọn đề tài}
            \hspace*{0.6cm}Trong các môi trường làm việc có rủi ro cao, nơi an toàn tuyệt đối không thể được đảm bảo, hệ thống chống rơi ngã cá nhân (Personal fall-arrest system - PFAS) đóng vai trò quan trọng trong việc bảo vệ người lao động khỏi ngã. Tuy nhiên, thiết bị thử nghiệm lỗi thời và quy trình không nhất quán có thể dẫn đến đánh giá độ bền không chính xác của dây đai an toàn, làm gia tăng rủi ro tại nơi làm việc.

            Vì vậy nhóm quyết định chọn đề tài, "Thiết kế máy thử nghiệm độ bền tĩnh cho dây đai an toàn," nhằm phát triển một hệ thống tiên tiến có khả năng đo lường chính xác độ bền tĩnh của dây đai an toàn để đảm bảo chúng đáp ứng các tiêu chuẩn chất lượng nghiêm ngặt. Công nghệ thử nghiệm hiện đại này không chỉ nâng cao an toàn và giảm chi phí liên quan đến tai nạn mà còn củng cố uy tín của nhà sản xuất và hỗ trợ sự phát triển của ngành thông qua việc cải thiện kiểm soát chất lượng và tiêu chuẩn hóa thử nghiệm.
        \subsection{Các khái niệm chính}
            \hspace*{0.6cm}Một số khái niệm được sử dụng để thử nghiệm theo TCVN 7802-1:2007:
            \begin{itemize}
                \item Các khái niệm liên quan đến dây đeo cả người:
                \begin{figure}[H]
                    \centering
                    
                    \caption{Ví dụ của dây đeo cả người}
                    \label{fig:label}
                \end{figure}
                \begin{itemize}
                    \item \textbf{Dây đỡ cả người (DĐCN):} Bộ phận của thiết bị đỡ cả người để giữ người ở trong hệ thống chống rơi ngã cá nhân.
                    
                    \item \textbf{Dây chính:} Dây thuộc dây đỡ cả người được chế tạo để truyền tải, đỡ cơ thể người hoặc làm giảm áp lực lên người trong quá trình rơi và sau khi sự rơi kết thúc.
                    
                    \item \textbf{Dây phụ:} Dây được thiết kế cùng với DĐCN, không phải dây chính.
                    
                    \item \textbf{Chi tiết liên kết chống rơi ngã:} Phụ kiện bắt buộc, được thiết kế như điểm liên kết để kết nối với hệ thống chống rơi ngã.
                    
                    \item \textbf{Khóa nhanh:} Phụ kiện gồm hai phần được thiết kế để dễ dàng đeo và tháo DĐCN.
                \end{itemize}
                \item Các khái niệm liên quan đến hệ thống: \\[0.2cm]
                \hspace*{0.6cm}Hệ thống chống rơi ngã cá nhân (personal fall-arrest system) - HTCRN: Hệ thống được thiết kế để chống rơi ngã từ trên cao, giảm thiểu xung lực khi rơi, kiểm soát toàn bộ khoảng cách rơi để ngăn ngừa việc va vào nền đất hoặc vật cản khác và để giữ người rơi xuống trong một tư thế thích hợp.
                \item Một số yêu cầu đối với dây đai toàn thân:
                \begin{itemize}
                    \item Tất cả DĐCN phải tối thiểu là loại A đối với mục đích chống rơi ngã.
                    
                    \item DĐCN loại A được thiết kế để đỡ cơ thể người trong và sau khi sự rơi kết thúc. Chúng phải có ít nhất một chi tiết liên kết chống rơi ngã. Chi tiết liên kết chống rơi ngã phải được bố trí sao cho nó đặt ở phía sau của người đeo và chính giữa hai dây quàng vai trên, hoặc ở giữa phần trước ngực không gần nhiều cao của xương ức.
                    
                    \item Tất cả các chi tiết liên kết làm móc treo của vật liệu dệt phải được bảo vệ thích hợp để chống mài mòn, cả ở trong và ngoài móc.
                    
                    \item Tuỳ thuộc vào sự phân loại DĐCN, các chi tiết liên kết phải được gắn vào DĐCN ở những vị trí được quy định ở 4.2. Theo tiêu chuẩn này, những điểm liên kết ở phía trước và phía bên cạnh để kết nối với hệ thống tai vị trí làm việc không được chấp nhận để sử dụng chống rơi ngã.
                    
                    \item Chi tiết liên kết chống rơi ngã của DĐCN loại A, khi đặt ở lưng của người đeo và chính giữa hai vai, phải được thiết kế sao cho không trượt xuống lưng của mẫu thử mô phỏng theo nửa thân người trong khi thử động quay ngược.
                \end{itemize}
                \item Yêu cầu về độ bền tĩnh để đảm bảo an toàn cho người sử dụng
                \begin{itemize}
                    \item Dây đai toàn thân phải chịu được lực 15 kN trong quá trình thử nghiệm.
                    \item Không xé rách vật liệu vải làm đai.
                    \item Không làm đứt đường may ở bất kỳ điểm nào.
                    \item Không gãy một phần hoặc toàn bộ của bất kỳ khóa nào.
                    \item Không mở ngoài ý muốn của bất kỳ khóa mở nhanh nào.
                    \item Các dây và các chi tiết liên kết không được di chuyển lệch khỏi vị trí. Các dây được phép trượt qua khóa điều chỉnh, những không quá 25mm.
                \end{itemize}
            \end{itemize}

    \section{Phương pháp thử nghiệm TCVN 7802-1:2007}
        \hspace*{0.6cm}Theo Mục 5 của TCVN 7802-1:2007 về Phương pháp Thử nghiệm, trong Mục 5.1 "Thiết bị" bao gồm: 5.1.1 "Mẫu thử mô phỏng theo nửa thân người để thử tĩnh", 5.1.4 "Giá thử", 5.1.5 "Thiết bị thử độ bền tĩnh", 5.1.8 "Dụng cụ đo lực". Trong Mục 5.4 "Thử độ bền tĩnh đối với các chi tiết liên kết chống rơi ngã" có cung cấp quy định về quy trình thử nghiệm và kết quả các kết quả cần ghi nhận ghi nhận trong quá trình thử nghiệm độ bền tĩnh.
        \subsection{Quy định về mẫu thử:}
            Hình nộm nửa người mô phỏng để thử nghiệm tĩnh phải phù hợp với kích thước được thể hiện trong hình bên dưới. Đinh khuy treo phải có đường kính trong là 40 mm và đường kính mặt cắt ngang tối đa là 16 mm. Bề mặt làm nhẵn, và nếu là kết cấu bằng gỗ, bề mặt phải được đánh bóng bằng senlắc hoặc vécni.
            \begin{figure}[H]
                \centering
                
                \caption{Hình nộm mô phỏng nửa thân người để thử tĩnh}
                \label{fig:label}
            \end{figure}
        \subsection{Một số quy định về giá thử:}
            \begin{itemize}
                \item Có kết cấu neo cứng vững, sao cho tần số rung tự nhiên theo trục thẳng đứng tại điểm móc dây không vượt quá 100 Hz và sao cho khi tác dụng một lực 20 kN trên điểm móc dây không gây chuyển vị lớn hơn 1 mm;
                
                \item Điểm móc dây phải là một vòng tròn có đường kính lỗ là (20 $\pm$ 1) mm và đường kính mặt cắt ngang là (15 $\pm$ 1) mm, hoặc một thanh truyền có đường kính mặt cắt ngang tương tự;
                
                \item Điểm móc dây phải có độ cao đủ để giữ được mẫu thử mô phỏng theo nửa thân người không bị rơi xuống sàn trong khi thử động.
            \end{itemize}

        \subsection{Quy định về thiết bị thử độ bền tĩnh:}
            \begin{itemize}
                \item Bao gồm một khung thử, tời hoặc cơ cấu thủy lực, đồng hồ đo, và một thanh ngang phù hợp để tạo được tải lên mẫu thử mô phỏng theo nửa thân người.
            \end{itemize}
        \subsection{Quy định về dụng cụ đo lực:}
            \begin{itemize}
                \item Phải có khả năng đo lực từ 1.2 kN đến 20 kN, với độ chính xác $\pm$ 2\%.
            \end{itemize}
        \subsection{Quy định về phương pháp thử nghiệm:}

            \begin{itemize}
                \item Lắp dây đai toàn thân lên hình nộm nửa người mô phỏng theo cách tương tự như mặc trên người, tuân theo hướng dẫn của nhà sản xuất. Điều chỉnh để đảm bảo dây đai ôm sát trên hình nộm.
                
                \item Đánh dấu vật liệu dây đai tại mỗi khóa điều chỉnh và khung khóa cài để các vết đánh dấu này được căn chỉnh.
                
                \item Tác dụng lực kéo 15 kN giữa phần tử gắn kết chống rơi và chốt treo dưới của hình nộm, với thời gian đạt đến lực này là (4 $\pm$ 1) phút. Duy trì lực trong 3 phút.
            \end{itemize}
        \subsection{Một số quy định về đánh giá kết quả:}
            \hspace*{0.6cm}Quan sát và ghi nhận nếu có:
            \begin{itemize}
                \item Xé rách vật liệu vải làm đai
                \item Làm đứt một phần hoặc toàn bộ đường may ở bất kỳ điểm nào
                \item Gãy một phần hoặc toàn bộ của bất kỳ khóa điều chỉnh hoặc khóa nhanh nào
                \item Mở ra ngoài ý muốn của bất kỳ khóa nhanh nào
                \item Dịch chuyển lệch của các dây và các chi tiết liên kết khỏi vị trí ban đầu
                \item Lệch hàng của những dấu khóa
            \end{itemize}
    \section{Thiết bị hiện có trên thị trường}
        \hspace*{0.6cm}Hiện tại, máy thử độ bền tĩnh cho dây đai theo TCVN 7802 (ISO 10333) chưa được sử dụng rộng rãi. Điều này chủ yếu do tính chất đặc thù của phương pháp thử nghiệm và nhu cầu thực tế từ các nhà sản xuất và cơ quan chứng nhận.

        Thông thường, để đánh giá khả năng chịu tải và đảm bảo an toàn cho dây đai toàn thân, các nhà sản xuất ưu tiên sử dụng các hệ thống thử độ bền động quy mô lớn. Các hệ thống này mô phỏng các điều kiện thực tế khi một người sử dụng dây đai ở độ cao hoặc trong các tình huống có nguy cơ rơi tự do. Các bài thử nghiệm bao gồm mô phỏng rơi tự do với tải trọng hình nộm, đánh giá lực va đập tức thời, và độ giãn dài của dây đai dưới tải trọng.

        Hơn nữa, do các yêu cầu nghiêm ngặt về an toàn và độ tin cậy, các hệ thống thử nghiệm động được thiết kế với cấu trúc vững chắc có khả năng kiểm soát chính xác các thông số như gia tốc, lực căng, và thời gian va đập. Các hệ thống này không chỉ đánh giá chất lượng sản phẩm một cách toàn diện mà còn hỗ trợ các nhà sản xuất cải thiện thiết kế và tối ưu hóa vật liệu để đáp ứng các tiêu chuẩn an toàn nghiêm ngặt.

        \begin{figure}[H]
            \centering
            
            \caption{Ví dụ về hệ thống thử nghiệm tải trọng động cho dây bảo hộ}
            \label{fig:label}
        \end{figure}

        Đối với thử nghiệm độ bền tĩnh, máy nén kéo vạn năng (universal testing machines - UTMs) được sử dụng phổ biến trên thị trường để đánh giá chất lượng của dây đỡ cả người. Các máy này được thiết kế để thực hiện các thử nghiệm kéo, nén và uốn trên các loại vật liệu khác nhau, bao gồm dây đai an toàn trong lĩnh vực an toàn lao động.

        Tuy nhiên, do các đặc thù của TCVN 7802 (ISO 10333), hầu hết các máy này chỉ có thể thử nghiệm các bộ phận riêng lẻ của dây đỡ cả người thay vì toàn bộ hệ thống trong điều kiện thực tế. Để phù hợp với thử nghiệm dây đỡ cả người, các máy UTM thường được trang bị các kẹp chuyên dụng để kiểm tra độ bền của các bộ phận chính như:

        \begin{itemize}
            \item Dây đai chính: Xác định độ bền kéo và độ bền dưới tải trọng cao.
            \item Khóa mở nhanh: Đánh giá độ bền của khóa cài dưới lực tác động đột ngột hoặc kéo dài.
            \item Khóa điều chỉnh: Kiểm tra khả năng giữ cố định và không trượt trong quá trình sử dụng kéo dài.
            \item Dây đai kết nối: Đảm bảo độ bền và an toàn khi được kết nối với các điểm neo.
        \end{itemize}

        Mặc dù các máy kéo nén vạn năng có thể cung cấp kết quả chính xác cho các bộ phận riêng lẻ, chúng không thể mô phỏng hoàn toàn các điều kiện sử dụng thực tế của dây đai toàn thân. Điều này khiến chúng không thể thay thế hoàn toàn các hệ thống thử nghiệm chuyên dụng để đánh giá toàn bộ dây đai theo TCVN 7802.

        \subsection{Máy thử độ bền kéo dây đai an toàn XJS108C}
            \hspace*{0.6cm}Máy thử độ bền kéo dây đai an toàn XJ8108C, được thiết kế và sản xuất bởi Xiangjie Instrument, tuân thủ các tiêu chuẩn quốc gia GA 494-2004 cho thiết bị phòng cháy chữa cháy, GB6095-2009 cho dây đai an toàn, và GB/T6096-2009 cho phương pháp thử nghiệm dây đai an toàn.

            Thiết bị này được thiết kế đặc biệt để thử nghiệm độ bền kéo tĩnh của dây đai chính trong hệ thống dây đai an toàn, đánh giá chất lượng và an toàn theo các tiêu chuẩn nghiêm ngặt. Với độ chính xác cao, hoạt động ổn định và độ tin cậy đặc biệt, XJ8108C được sử dụng rộng rãi trong các trung tâm chứng nhận sản phẩm về an toàn lao động, cơ quan phòng cháy chữa cháy, và các đơn vị giám sát an toàn khác nhau. Thiết bị này không chỉ hỗ trợ chứng nhận chất lượng sản phẩm mà còn giúp các nhà sản xuất tối ưu hóa thiết kế và nâng cao hiệu suất của dây đai an toàn trong các ứng dụng thực tế. \\
            Sơ đồ nguyên lý của máy: 
            \begin{figure}[H]
                \centering
                
                \caption{Sơ đồ nguyên lý máy XJS108C}
                \label{fig:label}
            \end{figure}

            \begin{table}[H]
                \centering
                \caption{Thông số kỹ thuật máy XJ8108C}
                \begin{tabular}{|p{5cm}|p{9cm}|}
                    \hline
                    \textbf{Mã sản phẩm} & XJ8108C \\
                    \hline
                    \textbf{Màn hình} & PC \\
                    \hline
                    \textbf{Tải trọng tối đa} & 100 kN \\
                    \hline
                    \textbf{Độ phân giải lực} & $\pm$1/50000 \\
                    \hline
                    \textbf{Độ chính xác lực} & $\leq$$\pm$0.2\%F.S \\
                    \hline
                    \textbf{Hành trình thử} & 1000mm \\
                    \hline
                    \textbf{Tốc độ thử} & 0.01-500mm/phút \\
                    \hline
                    \textbf{Chế độ dừng} & Dừng quá tải, dừng khẩn cấp, dừng khi mẫu hỏng, dừng giới hạn hành trình trên/dưới, tự động quay về \\
                    \hline
                    \textbf{Hệ thống truyền động chính} & Servo AC với hộp giảm tốc, truyền động đai răng và vít me chính xác \\
                    \hline
                    \textbf{Công suất} & 1500 W \\
                    \hline
                    \textbf{Loại nguồn} & AC 220V 50/60Hz \\
                    \hline
                    \textbf{Kích thước (R x S x C)} & 800x550x 1950mm \\
                    \hline
                    \textbf{Trọng lượng} & 500kg \\
                    \hline
                \end{tabular}
                \label{tab:xj8108c_specs}
            \end{table}

        \subsection{Hệ thống thử độ bền kéo của công ty Fall Protection Laboratory (FPL)}
            \hspace*{0.6cm}Fall Protection Laboratory (FPL), có trụ sở tại Mexico, là một công ty chuyên về thử nghiệm thiết bị bảo vệ rơi, bao gồm dây đai toàn thân. Với danh tiếng vững chắc trong ngành, FPL là một trong những cơ sở thử nghiệm hàng đầu tại quốc gia này, được công nhận theo tiêu chuẩn năng lực phòng thí nghiệm ISO 17025 và tiêu chuẩn EMA của Mexico, đảm bảo các phép đo và đánh giá đáp ứng tiêu chuẩn chất lượng quốc tế.
            \begin{figure}[H]
                \centering
                
                \caption{Logo công ty Fall Protection Laboratory (FPL)}
                \label{fig:label}
            \end{figure}
            Mặc dù FPL không công khai thông số kỹ thuật chi tiết của các máy thử nghiệm độ bền tĩnh và động cho dây đai toàn thân, họ đã cung cấp nhiều hình ảnh về các hệ thống thử nghiệm của mình. Những hình ảnh này cho thấy các phương pháp thử nghiệm nghiêm ngặt và có hệ thống để đánh giá chất lượng sản phẩm. Trong thử nghiệm độ bền động, FPL sử dụng phương pháp mô phỏng rơi tự do để tái hiện các tình huống thực tế khi dây đai chịu tải trọng đột ngột. Hệ thống này đánh giá khả năng hấp thụ lực và độ bền của dây đai trong điều kiện khắc nghiệt, đảm bảo an toàn tối đa cho người sử dụng.

            Đối với thử nghiệm độ bền tĩnh, FPL sử dụng các máy kéo chuyên dụng để đánh giá từng bộ phận riêng lẻ của hệ thống dây đai toàn thân, bao gồm dây đai chính, khóa kết nối và dây cáp liên kết. Phương pháp này cho phép đánh giá chính xác khả năng chịu tải của từng bộ phận, đảm bảo tuân thủ các tiêu chuẩn an toàn nghiêm ngặt. Bằng cách thử nghiệm từng bộ phận riêng lẻ, FPL có thể xác định các điểm yếu tiềm ẩn, giúp các nhà sản xuất cải thiện thiết kế và nâng cao chất lượng sản phẩm trước khi đưa vào sử dụng thực tế.

            \begin{figure}[H]
                \centering
                
                \caption{Hệ thống thử độ bền kéo trong phòng thí nghiệm}
                \label{fig:label}
            \end{figure}

        \subsection{Máy thử dây đai an toàn điện tử KASON ETM504D}
            \begin{figure}[H]
                \centering
                
                \caption{KASON ETM504}
                \label{fig:label}
            \end{figure}   
            \hspace*{0.6cm}Máy thử nghiệm dây đai an toàn điện tử điều khiển bằng máy tính dòng ETM (Không gian kép) được thiết kế và sản xuất theo các tiêu chuẩn ASTM, ISO, DIN, v.v. Đây là máy thử nghiệm chính xác điều khiển bằng máy tính, phù hợp với nhiều loại vật liệu để thử nghiệm kéo, nén, uốn, cắt, v.v. Máy có độ ổn định cao cũng như độ chính xác cao, được trang bị hệ thống PC và máy in để hiển thị đồ thị, kết quả thử nghiệm, in ấn và xử lý dữ liệu. Hoàn chỉnh với mô-đun cho kim loại, lò xo, dệt may, cao su, nhựa và các vật liệu khác. Máy được sử dụng rộng rãi trong nhiều lĩnh vực như nhà máy công nghiệp, doanh nghiệp khai khoáng và các trường đại học. 
            \begin{table}[H]
                \centering
                \caption{Thông số kỹ thuật máy ETM 504D}
                \begin{tabular}{|p{6cm}|p{8cm}|}
                    \hline
                    \textbf{Mô hình} & ETM 504D \\
                    \hline
                    \textbf{Load cell} & \\
                    \hline
                    \textbf{Tiêu chuẩn hiệu chuẩn} & ISO 7500 \\
                    \hline
                    \textbf{Công suất tải (kN)} & 50 \\
                    \hline
                    \textbf{Cấp độ chính xác} & 0.5 \\
                    \hline
                    \textbf{Phạm vi lực thử nghiệm} & 0.2\%-100\%FS (toàn thang đo) \\
                    \hline
                    \textbf{Sai số chỉ báo lực thử} & Trong khoảng $\pm$0.5\% giá trị chỉ báo \\
                    \hline
                    \textbf{Độ phân giải lực thử} & $\pm$1/500000 lực thử tối đa, cấp độ không thay đổi và độ phân giải không đổi trong toàn bộ quá trình \\
                    \hline
                    \textbf{Phạm vi đo biến dạng} & Phạm vi đo biến dạng \\
                    \hline
                    \textbf{Sai số chỉ báo biến dạng} & Trong khoảng $\pm$0.5\% giá trị chỉ báo \\
                    \hline
                    \textbf{Độ phân giải biến dạng} & 1/300000 biến dạng tối đa \\
                    \hline
                    \textbf{Sai số chỉ báo dịch chuyển} & Trong khoảng $\pm$0.5\% giá trị chỉ báo \\
                    \hline
                    \textbf{Độ phân giải dịch chuyển} & 0.025$\mu$m \\
                    \hline
                    \textbf{Bộ điều khiển} & \\
                    \hline
                    \textbf{Tần số lấy mẫu} & Lên đến 1000 Hz \\
                    \hline
                    \textbf{Tần số điều khiển vòng kín} & Lên đến 1000Hz \\
                    \hline
                    \textbf{Độ phân giải} & 20 bit \\
                    \hline
                    \textbf{Phần mềm} & KASON TEST (Hỗ trợ tiếng Anh, tiếng Nga, tiếng Thổ Nhĩ Kỳ, v.v.) \\
                    \hline
                    \textbf{Khung chính} & \\
                    \hline
                    \textbf{Phạm vi tốc độ (mm/phút)} & 0.01-500 \\
                    \hline
                    \textbf{Độ chính xác tốc độ thử} & $\pm$0.5\% \\
                    \hline
                    \textbf{Không gian thử kéo (mm)} & 2500 \\
                    \hline
                    \textbf{Chiều rộng thử (mm)} & 700 \\
                    \hline
                    \textbf{Đĩa nén (mm)} & $\Phi$90mm \\
                    \hline
                    \textbf{Nguồn điện} & Đơn pha AC220V$\pm$10\%, 50Hz/60Hz \\
                    \hline
                    \textbf{Nhiệt độ hoạt động} & 0 đến +38$^{\circ}$ C \\
                    \hline
                \end{tabular}
                \label{tab:etm504d_specs}
            \end{table}

        \cleardoublepage
    \section{Mục tiêu, nhiệm vụ, phạm vi và phân công thiết kế}
        \subsection{Mục tiêu}
            \hspace*{0.6cm}Thiết kế và chế tạo thiết bị thử nghiệm độ bền tĩnh cho dây đỡ cả người với các yêu cầu sau:
            \begin{itemize}
                \item Thử nghiệm độ bền tĩnh của dây đỡ cả người.
                \item Đảm bảo kết quả thử nghiệm và quy trình tuân thủ TCVN 7802-1:2007.
            \end{itemize}
            
        \subsection{Nhiệm vụ}
            \begin{itemize}
                \item Phân tích và đề xuất sơ đồ nguyên lý, sơ đồ động học, và các phương án thiết kế cơ khí, điện, và điều khiển cho thiết bị.
                \item Tính toán và thiết kế các bộ phận cơ khí, bao gồm hệ thống truyền động và gá đỡ cảm biến, để đáp ứng các điều kiện thử nghiệm độ bền kéo quy định trong TCVN 7802-1:2007.
                \item Tính toán và thiết kế hệ thống điện của máy.
                \item Thiết kế hệ thống điều khiển thiết bị.
                \item Tạo mô hình 3D, bản vẽ lắp ráp cơ khí, bản vẽ điện, sơ đồ điều khiển, và mô hình thử nghiệm.
                \item Thử nghiệm và đánh giá thiết bị.
            \end{itemize}
            
        \subsection{Phạm vi đề tài}
            \begin{itemize}
                \item Thiết kế thiết bị thử nghiệm độ bền tĩnh cho dây đai toàn thân sử dụng trong an toàn lao động.
                \item Đảm bảo thiết bị tuân thủ quy định thử nghiệm TCVN 7802-1:2007.
            \end{itemize}
            
        \subsection{Phân công thiết kế}
            \hspace*{0.6cm}Thiết kế máy thử nghiệm độ bền tĩnh cho dây đai toàn thân theo TCVN 7802-1:2007 cho "Dây đai toàn thân" với các thông số kỹ thuật sau:
            \begin{itemize}
                \item Lực tối đa tác dụng lên dây đai an toàn: 15 kN.
                \item Phạm vi hoạt động của thiết bị đo lực: 1,2 kN đến 20 kN.
                \item Độ chính xác của thiết bị đo lực: $\pm$ 2\%.
                \item Có khả năng tăng lực lên 15 kN trong vòng 240 giây và duy trì lực trong 180 giây.
            \end{itemize}

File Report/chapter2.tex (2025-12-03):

\chapter{LỰA CHỌN PHƯƠNG ÁN}
    \section{Thông số đầu vào}
        \hspace*{0.6cm}Thiết kế máy thử nghiệm độ bền tĩnh cho dây đỡ cả người theo tiêu chuẩn TCVN 7802-1:2007 với các yêu cầu sau:
        \begin{itemize}
            \item Lực tối đa tác dụng lên dây đai: 15 kN.
            \item Phạm vi làm việc của thiết bị đo lực: từ 1{,}2 kN đến 20 kN.
            \item Độ chính xác của thiết bị đo lực: $\pm$ 2\%.
            \item Thời gian đạt lực: 240 giây, thời gian duy trì lực: 180 giây.
        \end{itemize}
    \section{Lựa chọn phương án cơ khí}
        \subsection{Lựa chọn cấu trúc máy}

            \hspace*{0.6cm}Dựa trên các máy thử nghiệm hiện có trên thị trường, các thiết kế cấu trúc chính để thử nghiệm độ bền tĩnh của dây đai an toàn có thể được phân loại như sau: 

            \subsubsection*{Máy thử nghiệm độ bền kéo dây đai an toàn XJ8108C} 

                \hspace*{0.6cm}Máy này sử dụng động cơ servo để truyền động cho cơ cấu trục vít -- bánh vít, chuyển động được truyền qua dây đai răng đến vít me chính xác. Đầu kẹp di động được bố trí theo cấu hình dầm công xôn và được dẫn hướng bằng ray trượt tuyến tính.

                Thiết kế này chủ yếu phù hợp để thử nghiệm độ bền kéo của vật liệu dây đai—đặc biệt là các loại vải được sử dụng trong dây an toàn—nhằm xác định khả năng chịu tải của chúng.
                \begin{figure}[H]
                    \centering
                    
                    \caption{Sơ đồ nguyên lý máy XJS108C}
                    \label{fig:label}
                \end{figure}

            \subsubsection*{Hệ thống thử độ bền kéo của công ty Fall Protection Laboratory}
                \hspace*{0.6cm}Mặc dù cấu trúc bên trong của máy này không được mô tả chi tiết, các tài liệu tham khảo trực quan cho thấy thiết kế. Sự khác biệt chính có thể nằm ở cơ cấu kẹp chặt và kích thước tổng thể của máy.
                \begin{figure}[H]
                    \centering
                    
                    \caption{Sơ đồ nguyên lý máy của công ty FPL}
                    \label{fig:label}
                \end{figure}
                Máy của Fall Protection LAB có kích thước lớn hơn và được trang bị nhiều loại kẹp chuyên dụng được thiết kế để thử nghiệm các thành phần riêng lẻ của hệ thống dây an toàn toàn thân, chẳng hạn như dây đai vải, khóa an toàn và dây giảm chấn.

                Bất chấp những khác biệt này, cả hai máy đều có chung một hạn chế: không có máy nào hiện tại có khả năng thử nghiệm toàn bộ hệ thống dây an toàn đỡ người như một tổng thể trong điều kiện làm việc thực tế. Điều này đặt ra một thách thức đáng kể trong việc đánh giá hiệu suất tổng thể và độ an toàn của các hệ thống dây an toàn tích hợp.
            \subsubsection*{Máy thử dây đai an toàn điện tử KASON ETM504D}
                \begin{figure}[H]
                    \centering
                    
                    \caption{Sơ đồ nguyên lý máy KASON ETM504D}
                    \label{fig:label}
                \end{figure}
            \subsubsection*{Yêu cầu theo tiêu chuẩn TCVN đối với nguyên lý máy}
                \hspace*{0.6cm}Theo tiêu chuẩn TCVN 7802-1:2007, mục 5 "Phương pháp thử", mục nhỏ 5.1.5 "Thiết bị thử độ bền tĩnh" quy định các thành phần cần thiết cho thiết bị thử nghiệm độ bền tĩnh, bao gồm:
                \begin{itemize}
                    \item Khung thử nghiệm
                    \item Tời hoặc cơ cấu thủy lực
                    \item Đồng hồ đo
                    \item Thanh ngang phù hợp để tạo được tải lên mẫu thử mô phỏng theo nửa thân người
                \end{itemize}
                \hspace*{0.6cm}Do đó, thiết kế cơ khí của máy phải tuân theo tiêu chuẩn TCVN và sử dụng cơ cấu tời làm cấu trúc chính của máy, điều này có hiệu quả về chi phí. Hơn nữa, trong máy này không cần có độ chính xác vị trí cao, chỉ cần độ chính xác cho lực và thời gian để đạt được lực đó. Với những yêu cầu này, chúng ta có thể giải quyết bằng cách sử dụng các thuật toán điều khiển như PID để đảm bảo điều khiển lực.
                Sơ đồ nguyên lý mà nhóm lựa chọn:
                \begin{figure}[H]
                    \centering
                    
                    \caption{Sơ đồ nguyên lý phương án lựa chọn}
                    \label{fig:label}
                \end{figure}
        \subsection{Lựa chọn tời kéo}

            \hspace*{0.6cm}Dựa vào trang web của công ty EMCÉ winches, các loại tời kéo có sẵn trên thị trường:
            \begin{itemize}
    \item Tời kéo điện
                \item Tời kéo thủy lực
                \item Tời kéo khí nén            
            \end{itemize}

            Mỗi loại có các ưu nhược điểm khác nhau:
            \begin{table}[H]
                \centering
                \caption{So sánh các loại tời}
                \begin{tabular}{|p{2cm}|p{6cm}|p{6cm}|}
                    \hline
                    \textbf{Loại tời} & \textbf{Ưu điểm} & \textbf{Nhược điểm} \\
                    \hline
                    Tời điện & 
                    \begin{itemize}[leftmargin=*,nosep]
                    \item Dễ kết nối với lưới điện dân dụng
                    \item Chống nước và bụi (lên đến IP67)
                    \item Có thể tích hợp hệ thống làm mát và cảm biến
                    \item Phù hợp cho các ứng dụng khác nhau
                    \item Dải công suất rộng
                    \end{itemize} &
                    \begin{itemize}[leftmargin=*,nosep]
                    \item Có thể cần thêm biến tần hoặc phanh cho một số ứng dụng
                    \item Hiệu suất thấp trong giảm tốc
                    \item Khả năng chịu tải thấp hơn so với tời thủy lực
                    \end{itemize} \\
                    \hline
                    Tời thủy lực &
                    \begin{itemize}[leftmargin=*,nosep]
                    \item Được ưu tiên khi có sẵn hệ thống thủy lực
                    \item Kích thước nhỏ gọn so với công suất đầu ra
                    \item Chống nước và bụi
                    \item Bền và đáng tin cậy
                    \item Thường được sử dụng cho các ứng dụng công suất/mô-men cao như hàng hải
                    \end{itemize} &
                    \begin{itemize}[leftmargin=*,nosep]
                    \item Thường ồn ào
                    \item Yêu cầu hệ thống thủy lực phức tạp
                    \item Chi phí lắp đặt cao hơn
                    \end{itemize} \\
                    \hline
                    Tời khí nén &
                    \begin{itemize}[leftmargin=*,nosep]
                    \item An toàn trong môi trường dễ nổ (dầu, khai thác mỏ, hóa chất)
                    \item Khả năng chịu quá tải tốt
                    \end{itemize} &
                    \begin{itemize}[leftmargin=*,nosep]
                    \item Điều khiển kém linh hoạt so với tời điện
                    \item Yêu cầu nguồn cung cấp khí nén
                    \end{itemize} \\
                    \hline
                \end{tabular}
            \end{table}

            \textbf{Yêu cầu đối với tời:}

            \begin{itemize}
            \item Phải cung cấp lực kéo 15kN thông qua hệ thống truyền động.
            \item Thời gian đạt lực: 240 giây, thời gian duy trì lực: 180 giây.
            \end{itemize}

            Đối với thiết kế máy thử nghiệm độ bền tĩnh, tời điện là lựa chọn tối ưu do khả năng đáp ứng yêu cầu lực kéo, điều khiển linh hoạt và phù hợp với điều kiện phòng thí nghiệm. Tời điện có thể tạo ra lực kéo ổn định, cho phép điều khiển tốc độ để đạt được lực yêu cầu trong vòng 240 giây theo tiêu chuẩn thử nghiệm.
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

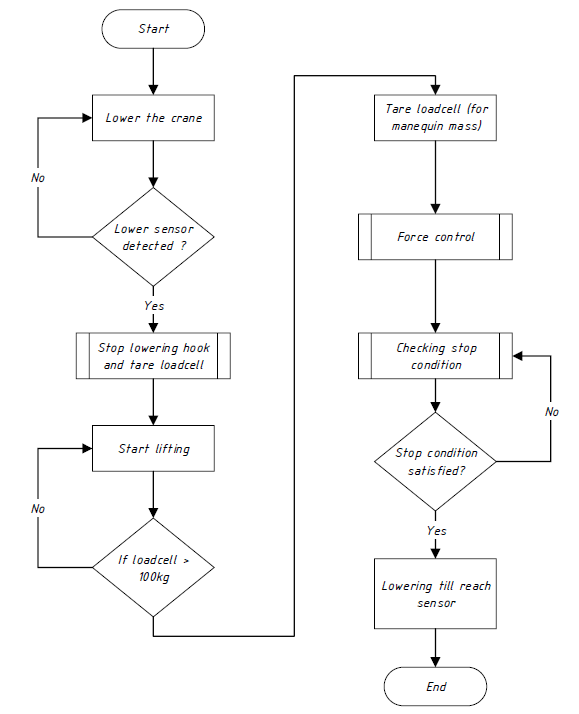
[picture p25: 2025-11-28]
Report/pictures/chapter2/c2_p07_luudogiaithuat.png

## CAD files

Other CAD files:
Drawing/Mechanical_Drawing.dwg
Drawing/Algorithms_Drawing.dwg
Drawing/Electrical_Drawing.dwg

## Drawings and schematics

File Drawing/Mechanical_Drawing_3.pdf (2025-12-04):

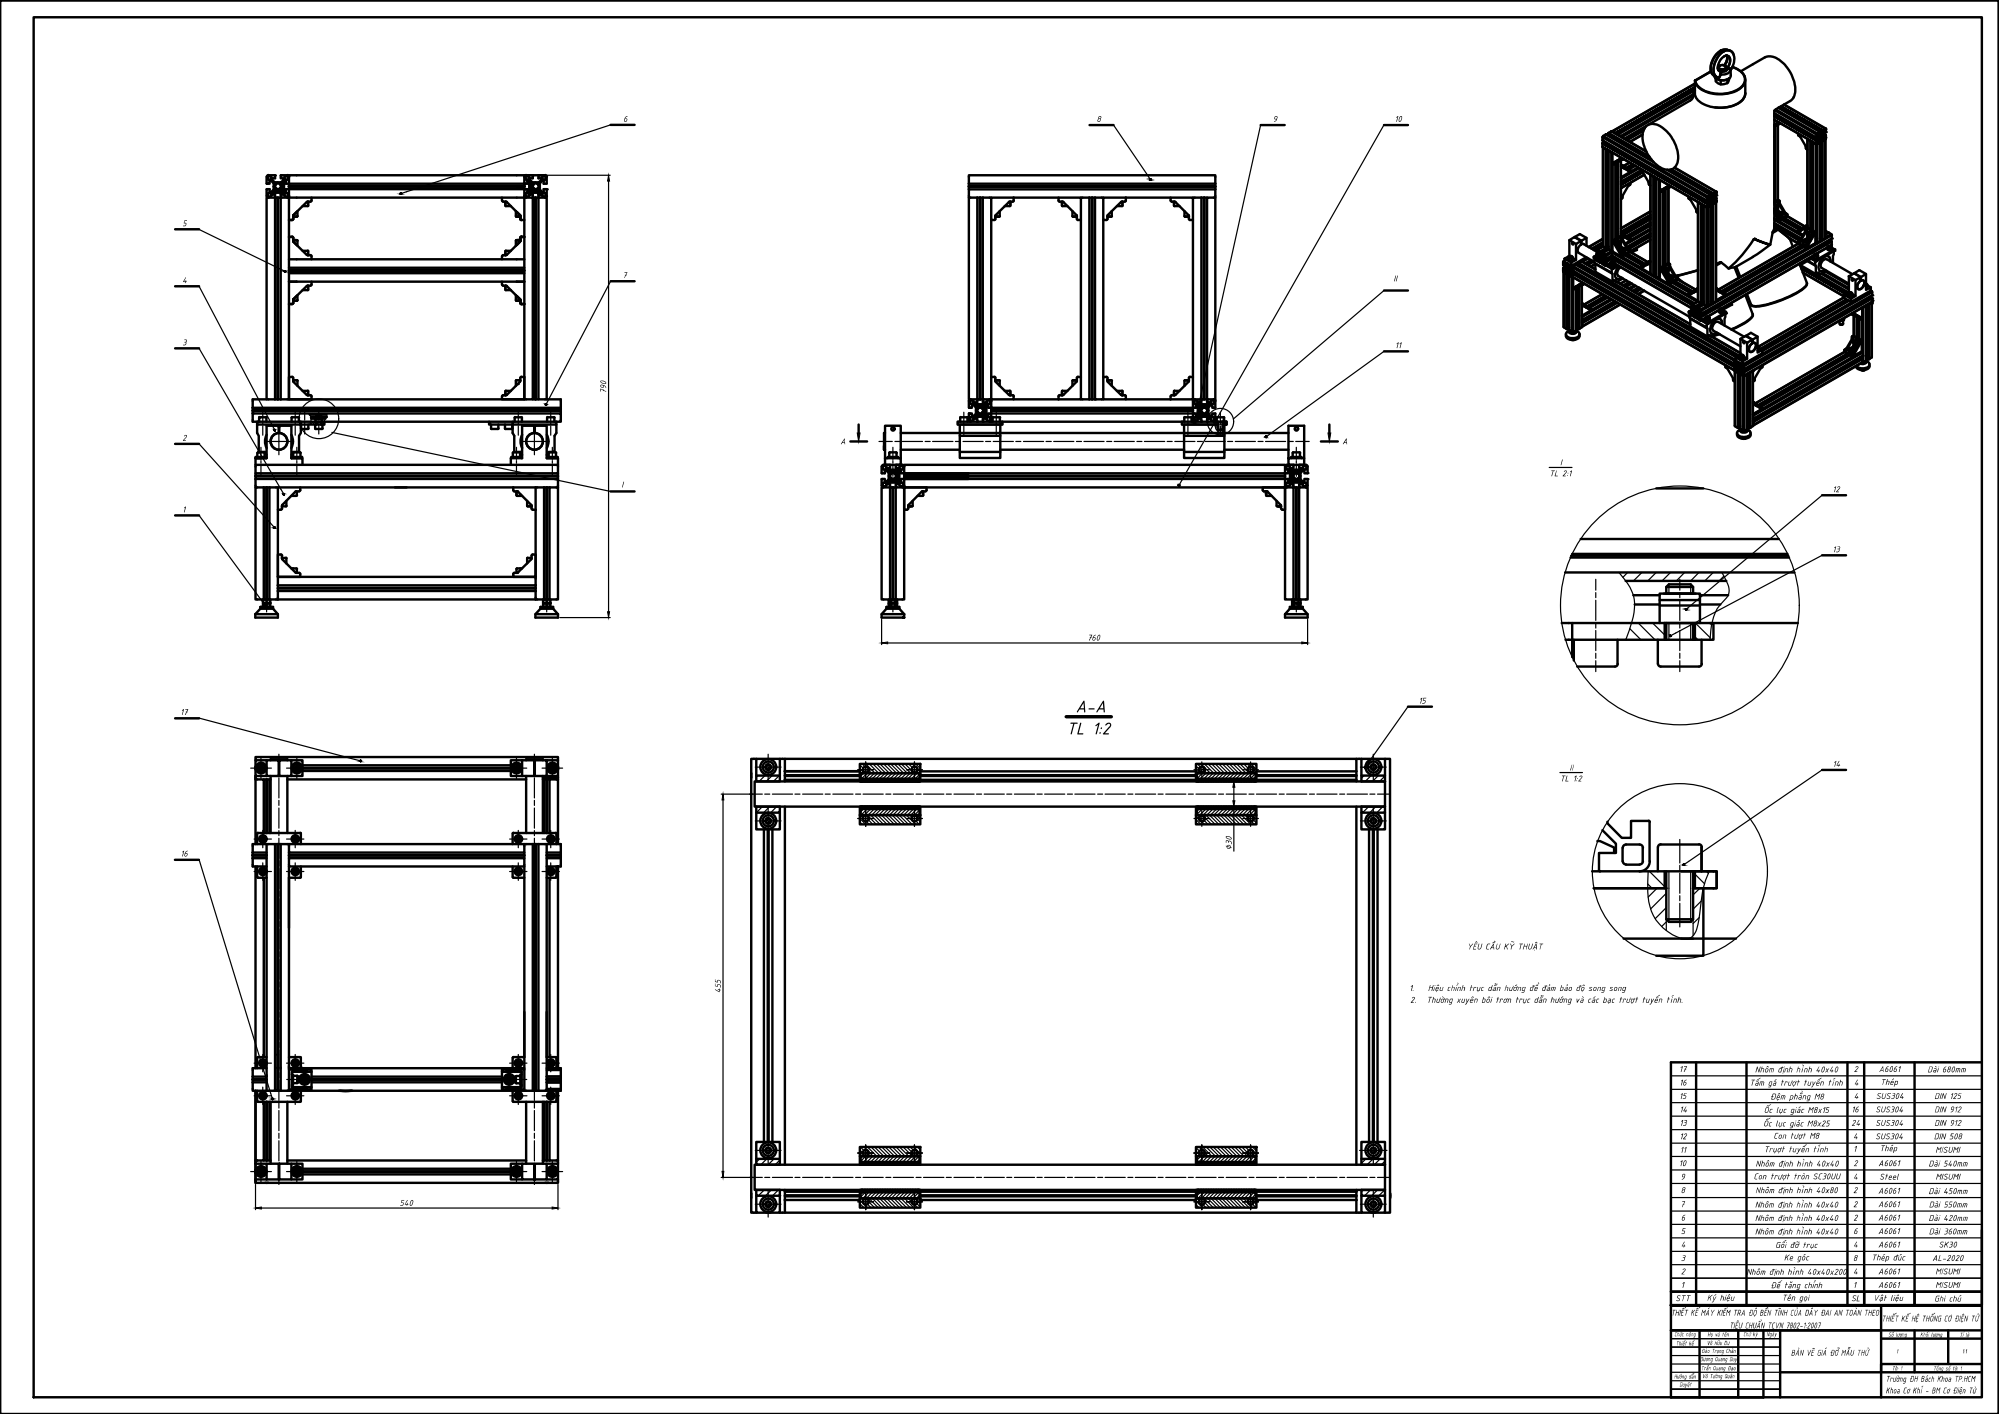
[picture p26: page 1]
STT; Ký hiệu; Tên gọi; Vật liệu; Ghi chú; Ke góc; Thép đúc; Đế tăng chỉnh; 1 Nhôm định hình 40x40x200 4; MISUMI; Gối đỡ trục; 2 Nhôm định hình 40x40; Con tượt M8; SUS304; Ốc lục giác M8x25; Ốc lục giác M8x15; Đệm phẳng M8; Thép; DIN 508; Dài 680mm; Dài 540mm; DIN 912 DIN 125; Dài 450mm; DIN 912; Dài 550mm; Dài 420mm; Dài 360mm; Họ và tên; Chữ ký; Ngày; Số lượng; Khối lượng; Tổng số tờ: 1

YÊU CẦU KỸ THUẬT

2. Thường xuyên bôi trơn trục dẫn hướng và các bạc trượt tuyến tính. 455

1. Hiệu chỉnh trục dẫn hướng để đảm bảo độ song song

Nhôm định hình 40x40
Tấm gá trượt tuyến tính

Trụợt tuyến tính

Con trượt tròn SC30UU
Nhôm định hình 40x80

THIẾT KẾ MÁY KIỂM TRA ĐỘ BỀN TĨNH CỦA DÂY ĐAI AN TOÀN THEO

TIÊU CHUẨN TCVN 7802-1:2007

THIẾT KẾ HỆ THỐNG CƠ ĐIỆN TỬ

Chức năng Thiết kế

Võ Hữu Dư Đào Trọng Chân Dương Quang Duy Trần Quang Đạo Võ Tường Quân

1:1 BẢN VẼ GIÁ ĐỠ MẪU THỬ

1 Trường ĐH Bách Khoa TP.HCM

Hướng dẫn Duyệt

Khoa Cơ Khí - BM Cơ Điện Tử

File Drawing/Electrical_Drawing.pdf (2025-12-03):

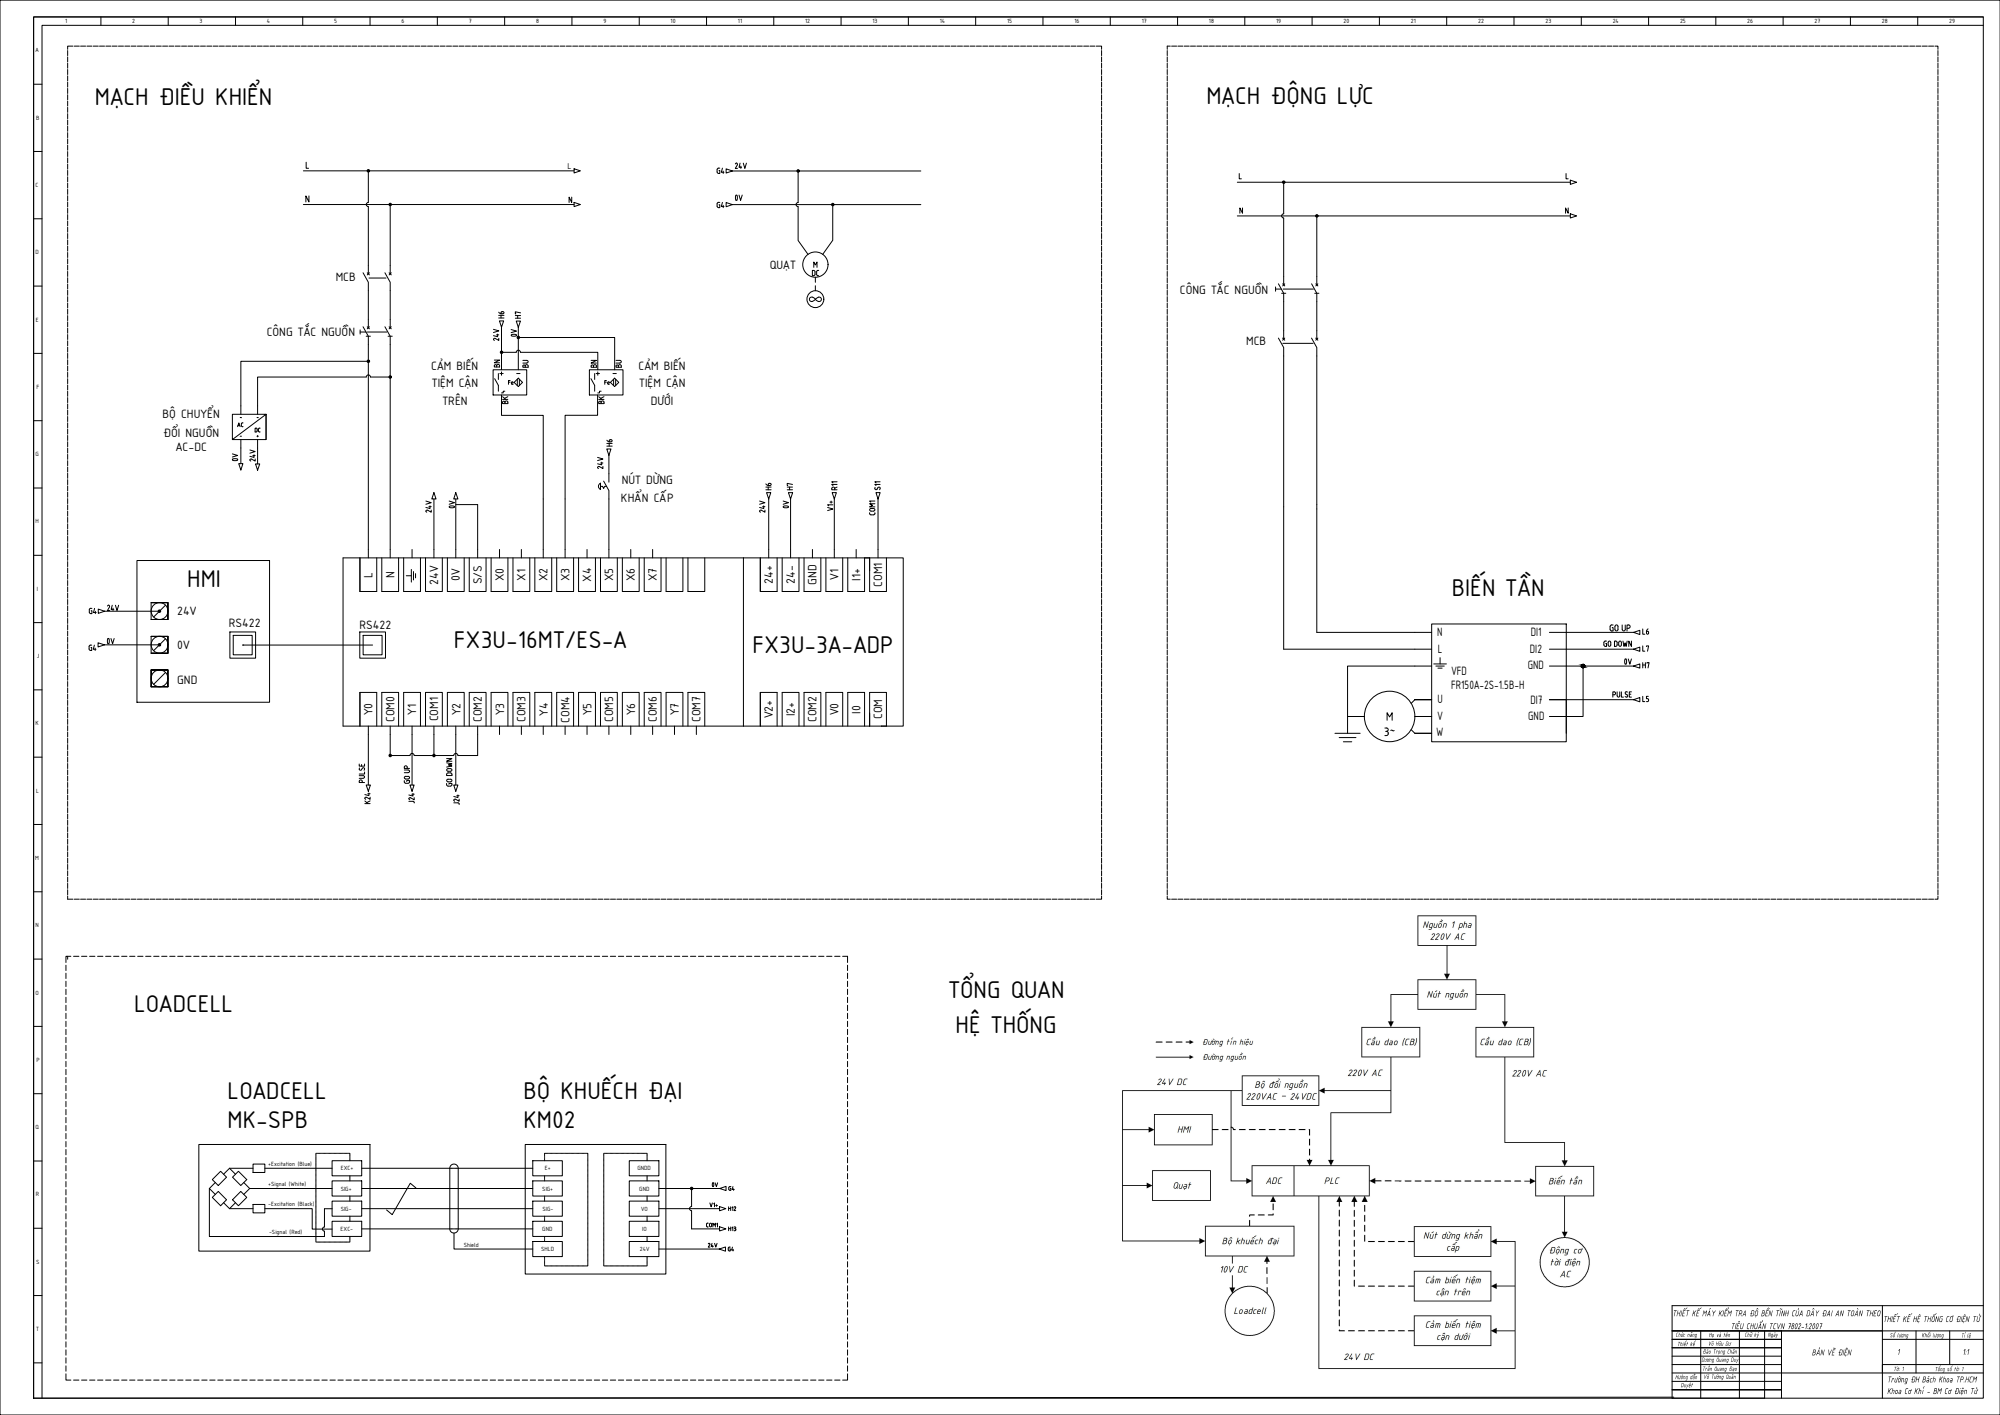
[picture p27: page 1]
29 COM0; FX3U-3A-ADP X5; GND Y0; COM1; COM2; COM3; COM4; COM5; COM6; COM7; I1+ GND V2+; I0 COM2; COM1 COM; +Excitation (Blue); +Signal (White); -Excitation (Black); -Signal (Red); MẠCH ĐIỀU KHIỂN; MẠCH ĐỘNG LỰC; BIẾN TẦN; TỔNG QUAN; HỆ THỐNG; BỘ CHUYỂN; ĐỔI NGUỒN; NÚT DỪNG; KHẨN CẤP; CẢM BIẾN; TIỆM CẬN; Họ và tên; Chữ ký; Ngày; Số lượng; Khối lượng; BẢN VẼ ĐIỆN

CÔNG TẮC NGUỒN

BỘ KHUẾCH ĐẠI

THIẾT KẾ MÁY KIỂM TRA ĐỘ BỀN TĨNH CỦA DÂY ĐAI AN TOÀN THEO

THIẾT KẾ HỆ THỐNG CƠ ĐIỆN TỬ

TIÊU CHUẨN TCVN 7802-1:2007

Chức năng
Thiết kế | Võ Hữu Dư | 1

Đào Trọng Chân
Dương Quang Duy
Trần Quang Đạo | Tờ: 1 | Tổng số tờ: 1

Hướng dẫn | Võ Tường Quân
Duyệt

Trường ĐH Bách Khoa TP.HCM
Khoa Cơ Khí - BM Cơ Điện Tử

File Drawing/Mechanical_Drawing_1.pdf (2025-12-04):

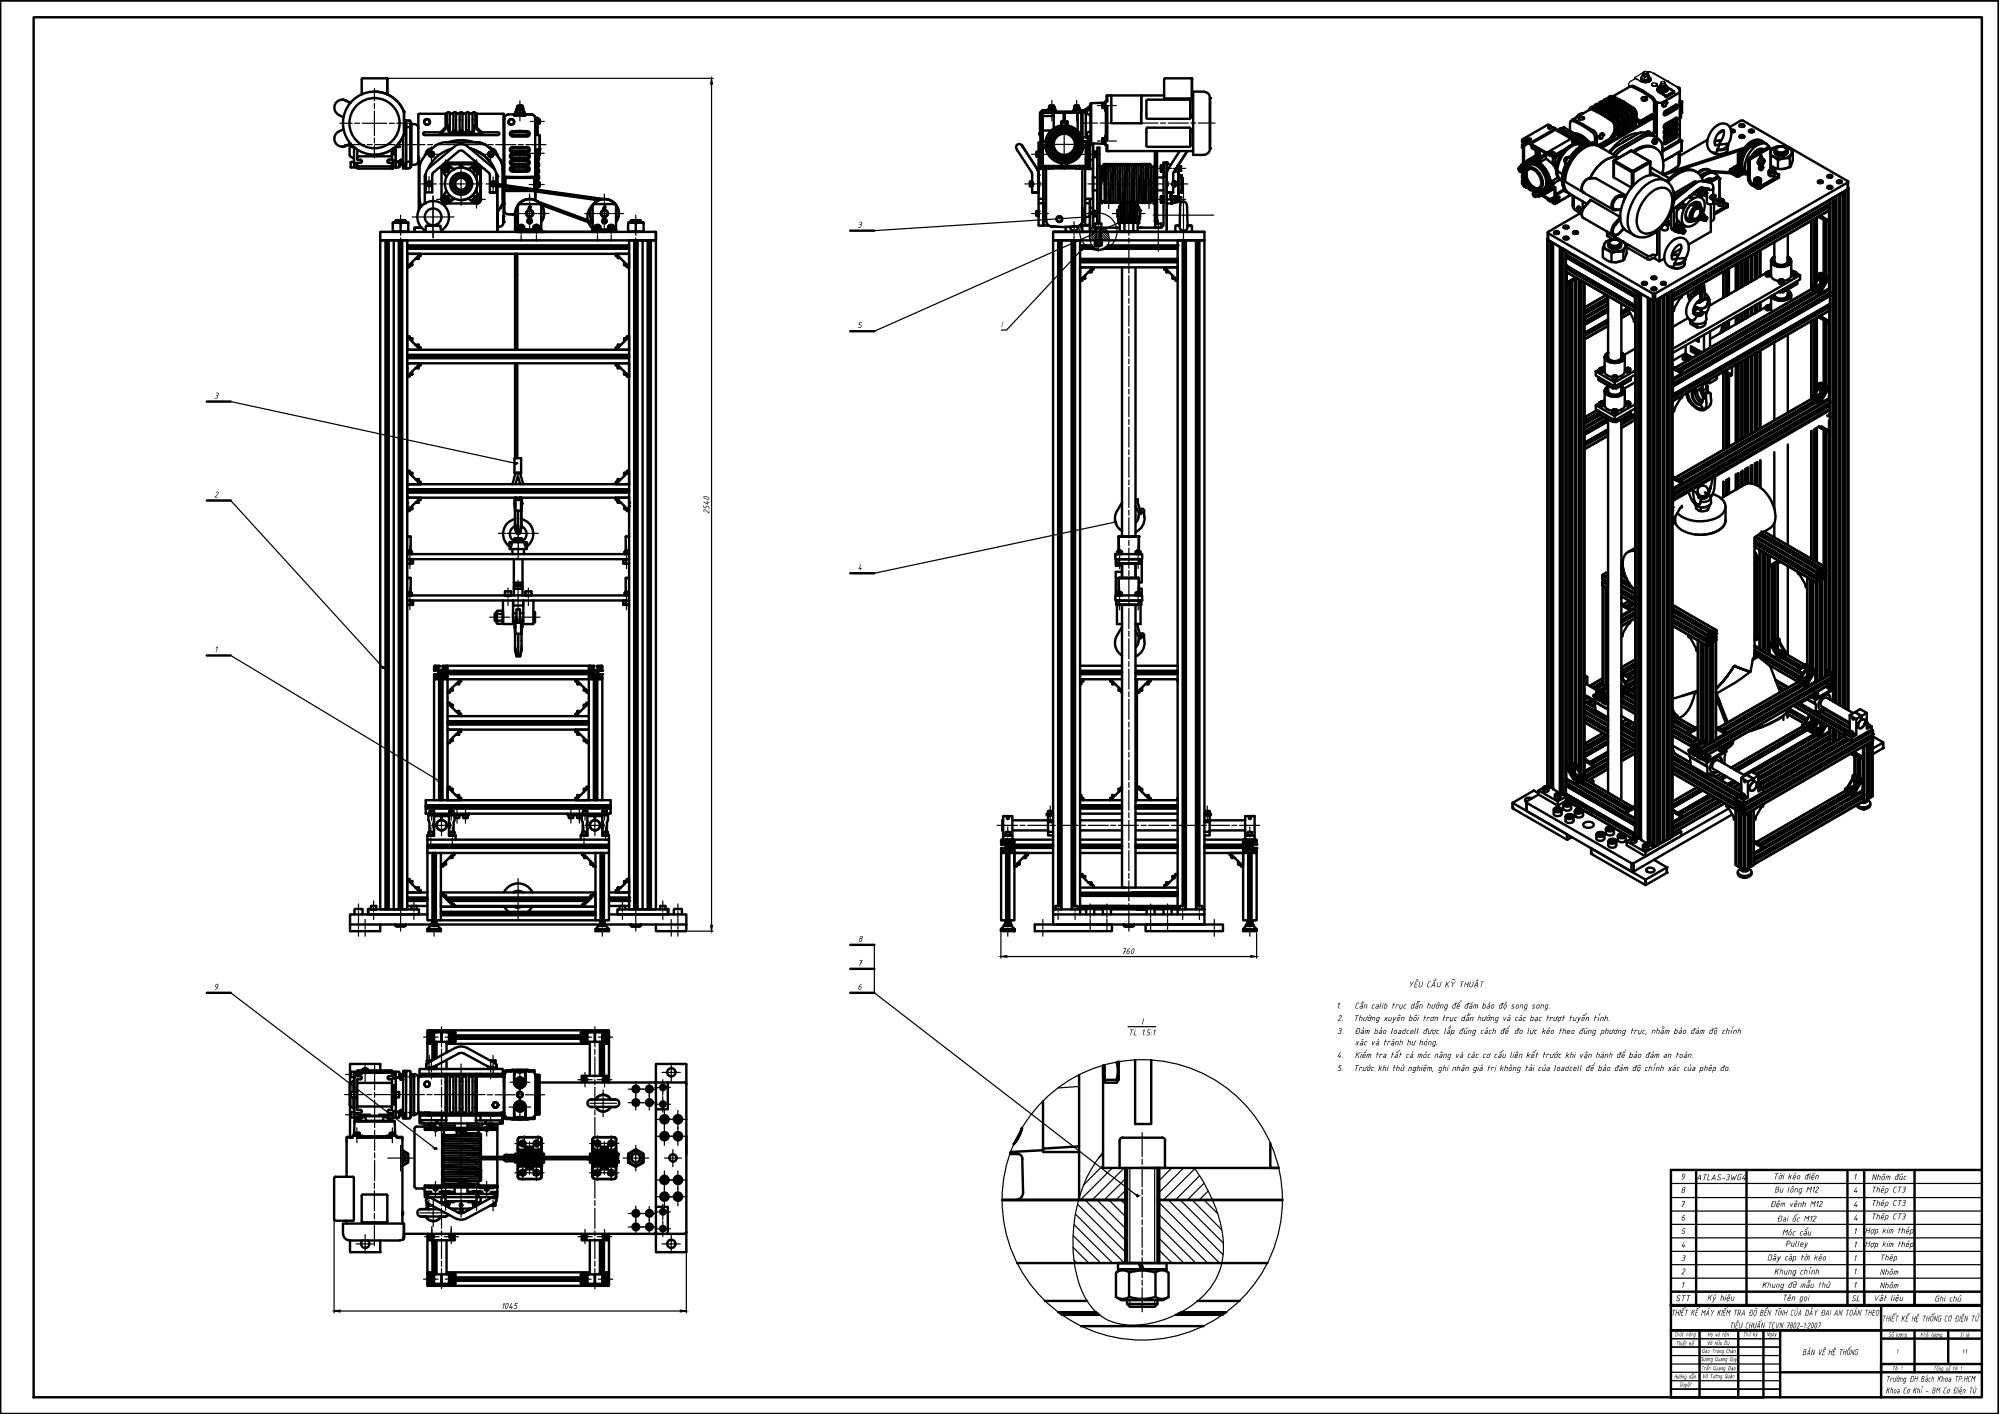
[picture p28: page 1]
Cần calib trục dẫn hướng để đảm bảo độ song song. 2.; Thường xuyên bôi trơn trục dẫn hướng và các bạc trượt tuyến tính. 3.; Đảm bảo loadcell được lắp đúng cách để đo lực kéo theo đúng phương trục, nhằm bảo đảm độ chính; xác và tránh hư hỏng. 4.; Kiểm tra tất cả móc nâng và các cơ cấu liên kết trước khi vận hành để bảo đảm an toàn. 5.; Trước khi thử nghiệm, ghi nhận giá trị không tải của loadcell để bảo đảm độ chính xác của phép đo.; STT; Ký hiệu; Tên gọi; Vật liệu; Ghi chú; Dây cáp tời kéo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

YÊU CẦU KỸ THUẬT

THIẾT KẾ MÁY KIỂM TRA ĐỘ BỀN TĨNH CỦA DÂY ĐAI AN TOÀN THEO

TIÊU CHUẨN TCVN 7802-1:2007

THIẾT KẾ HỆ THỐNG CƠ ĐIỆN TỬ

Chức năng Thiết kế

Võ Hữu Dư Đào Trọng Chân Dương Quang Duy Trần Quang Đạo Võ Tường Quân

1 Trường ĐH Bách Khoa TP.HCM

Hướng dẫn Duyệt

Khoa Cơ Khí - BM Cơ Điện Tử

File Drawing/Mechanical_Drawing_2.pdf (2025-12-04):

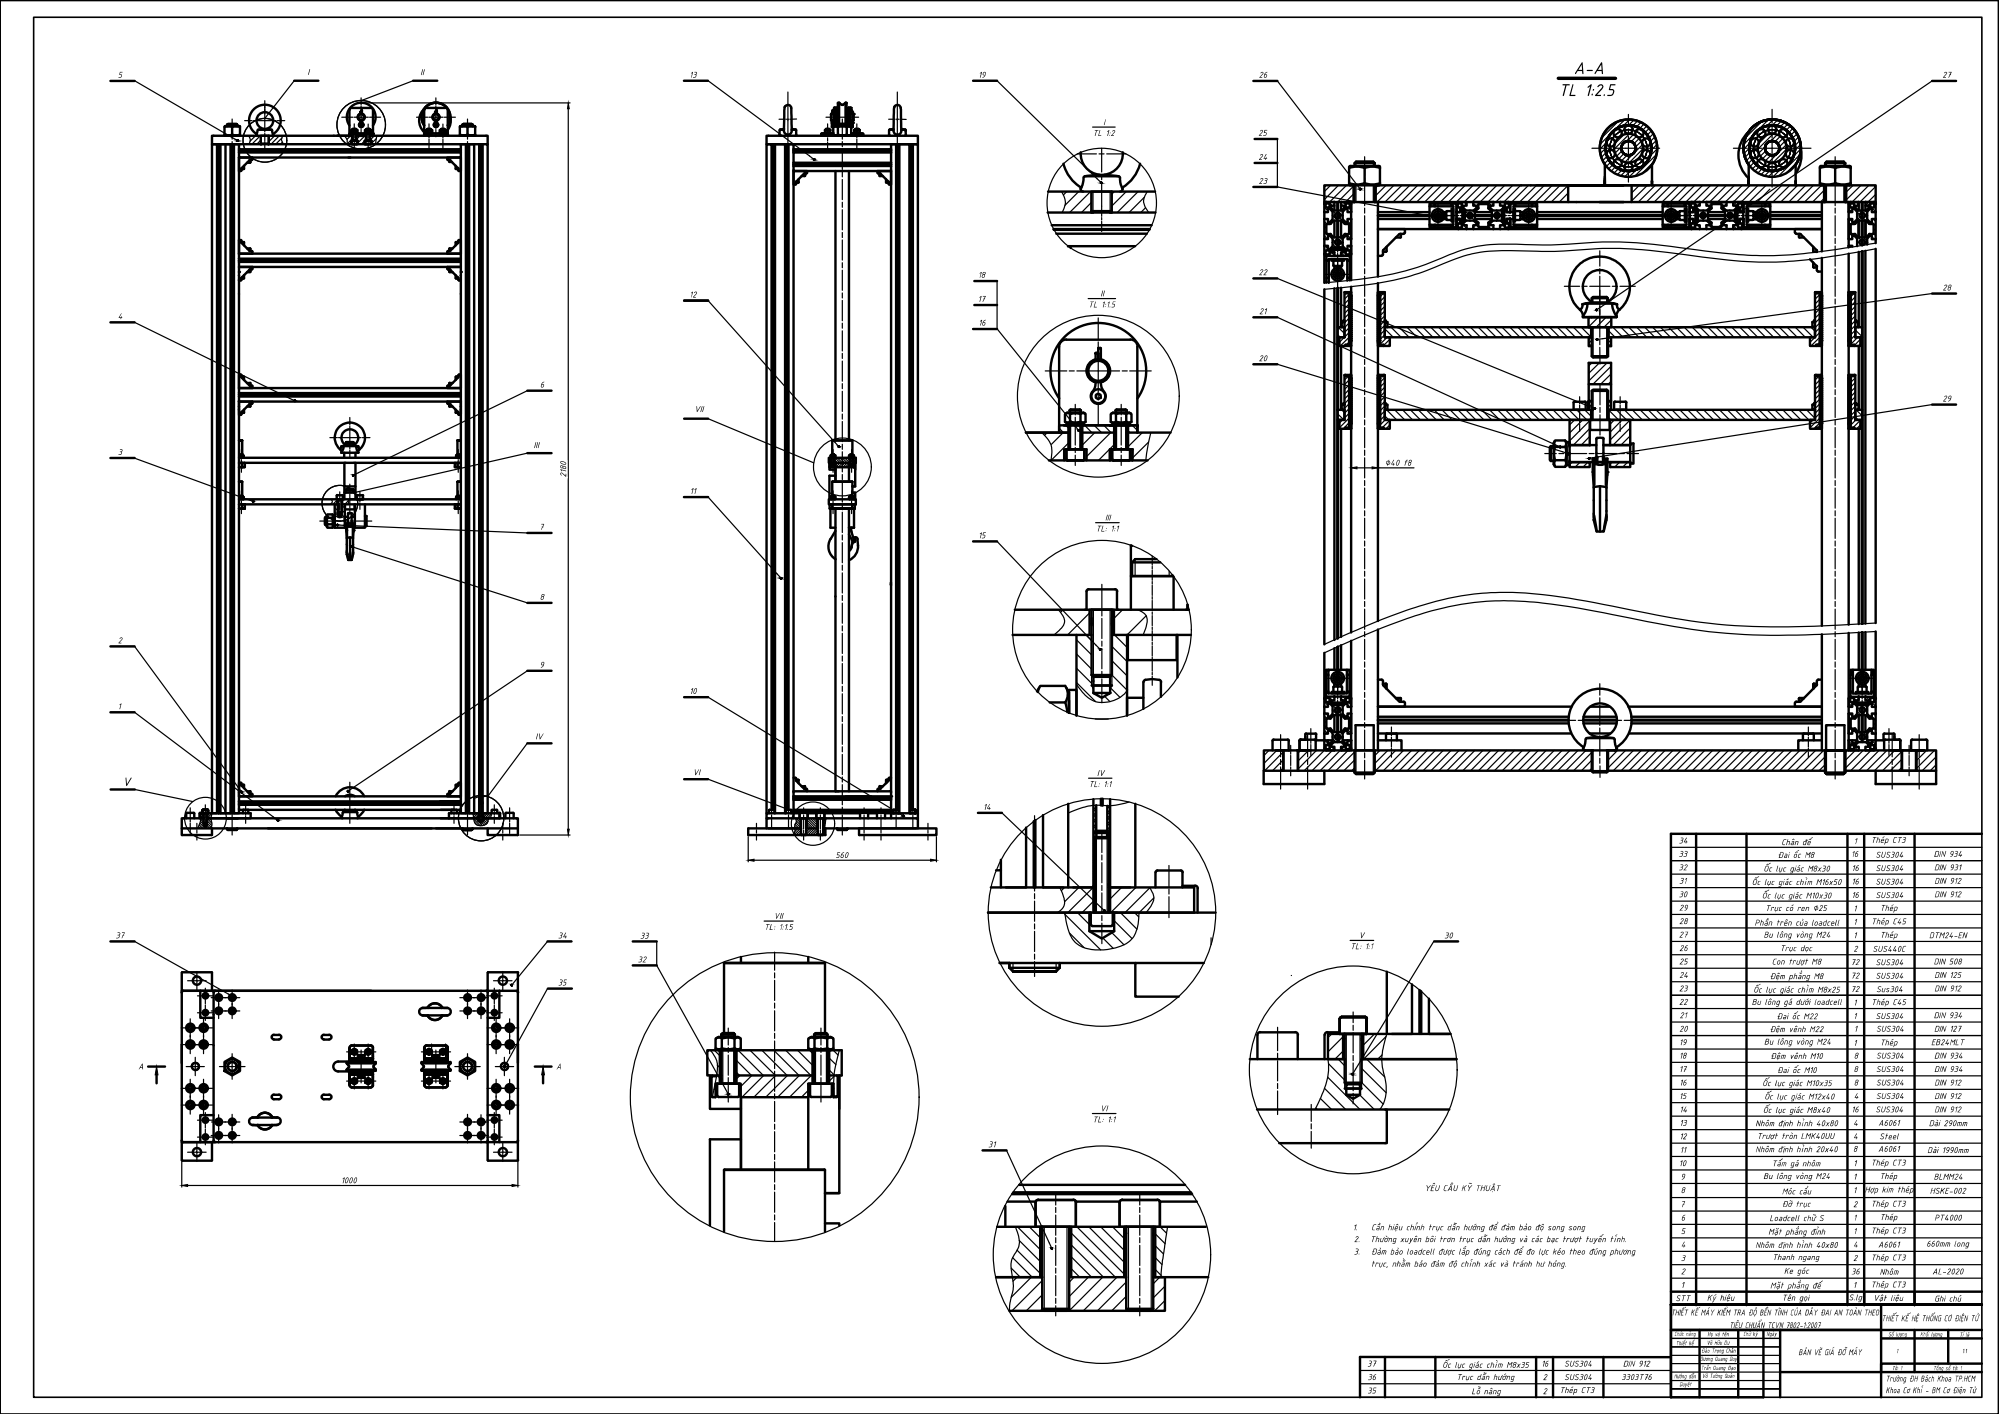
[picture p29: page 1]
III; STT; Ký hiệu; Tên gọi; Vật liệu; Ghi chú 123476589; Thanh ngang; Thép CT3; Mặt phẳng đế; Ke góc; Nhôm; Nhôm định hình 40x80; A6061 Mặt phẳng đỉnh; 1 Loadcell chữ S; Thép; PT4000 Đỡ trục; 2 Móc cẩu; Hợp kim thép; Bu lông vòng M24; Tấm gá nhôm; Nhôm định hình 20x40; A6061 Trượt tròn LMK40UU; Steel Nhôm định hình 40x80; Dài 290mm; Ốc lục giác M8x40; Ốc lục giác M10x35; SUS304; Ốc lục giác M12x40; Đai ốc M10; 8 Đệm vênh M10; Thép 8; HSKE-002 BLMM24; DIN 934; Trục dẫn hướng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

Chân đế
Đai ốc M8
Ốc lục giác M8x30
Ốc lục giác chìm M16x50
Ốc lục giác M10x30

Trục có ren ∅25
Phần trên của loadcell
Con trượt M8 Trục dọc Bu lông vòng M24

Đệm phẳng M8
Ốc lục giác chìm M8x25

Bu lông gá dưới loadcell

YÊU CẦU KỸ THUẬT

1. Cần hiệu chỉnh trục dẫn hướng để đảm bảo độ song song

trục, nhằm bảo đảm độ chính xác và tránh hư hỏng.

THIẾT KẾ MÁY KIỂM TRA ĐỘ BỀN TĨNH CỦA DÂY ĐAI AN TOÀN THEO

TIÊU CHUẨN TCVN 7802-1:2007

THIẾT KẾ HỆ THỐNG CƠ ĐIỆN TỬ

Chức năng Thiết kế

Võ Hữu Dư Đào Trọng Chân Dương Quang Duy Trần Quang Đạo Võ Tường Quân

Ốc lục giác chìm M8x35

Hướng dẫn Duyệt

Khoa Cơ Khí - BM Cơ Điện Tử

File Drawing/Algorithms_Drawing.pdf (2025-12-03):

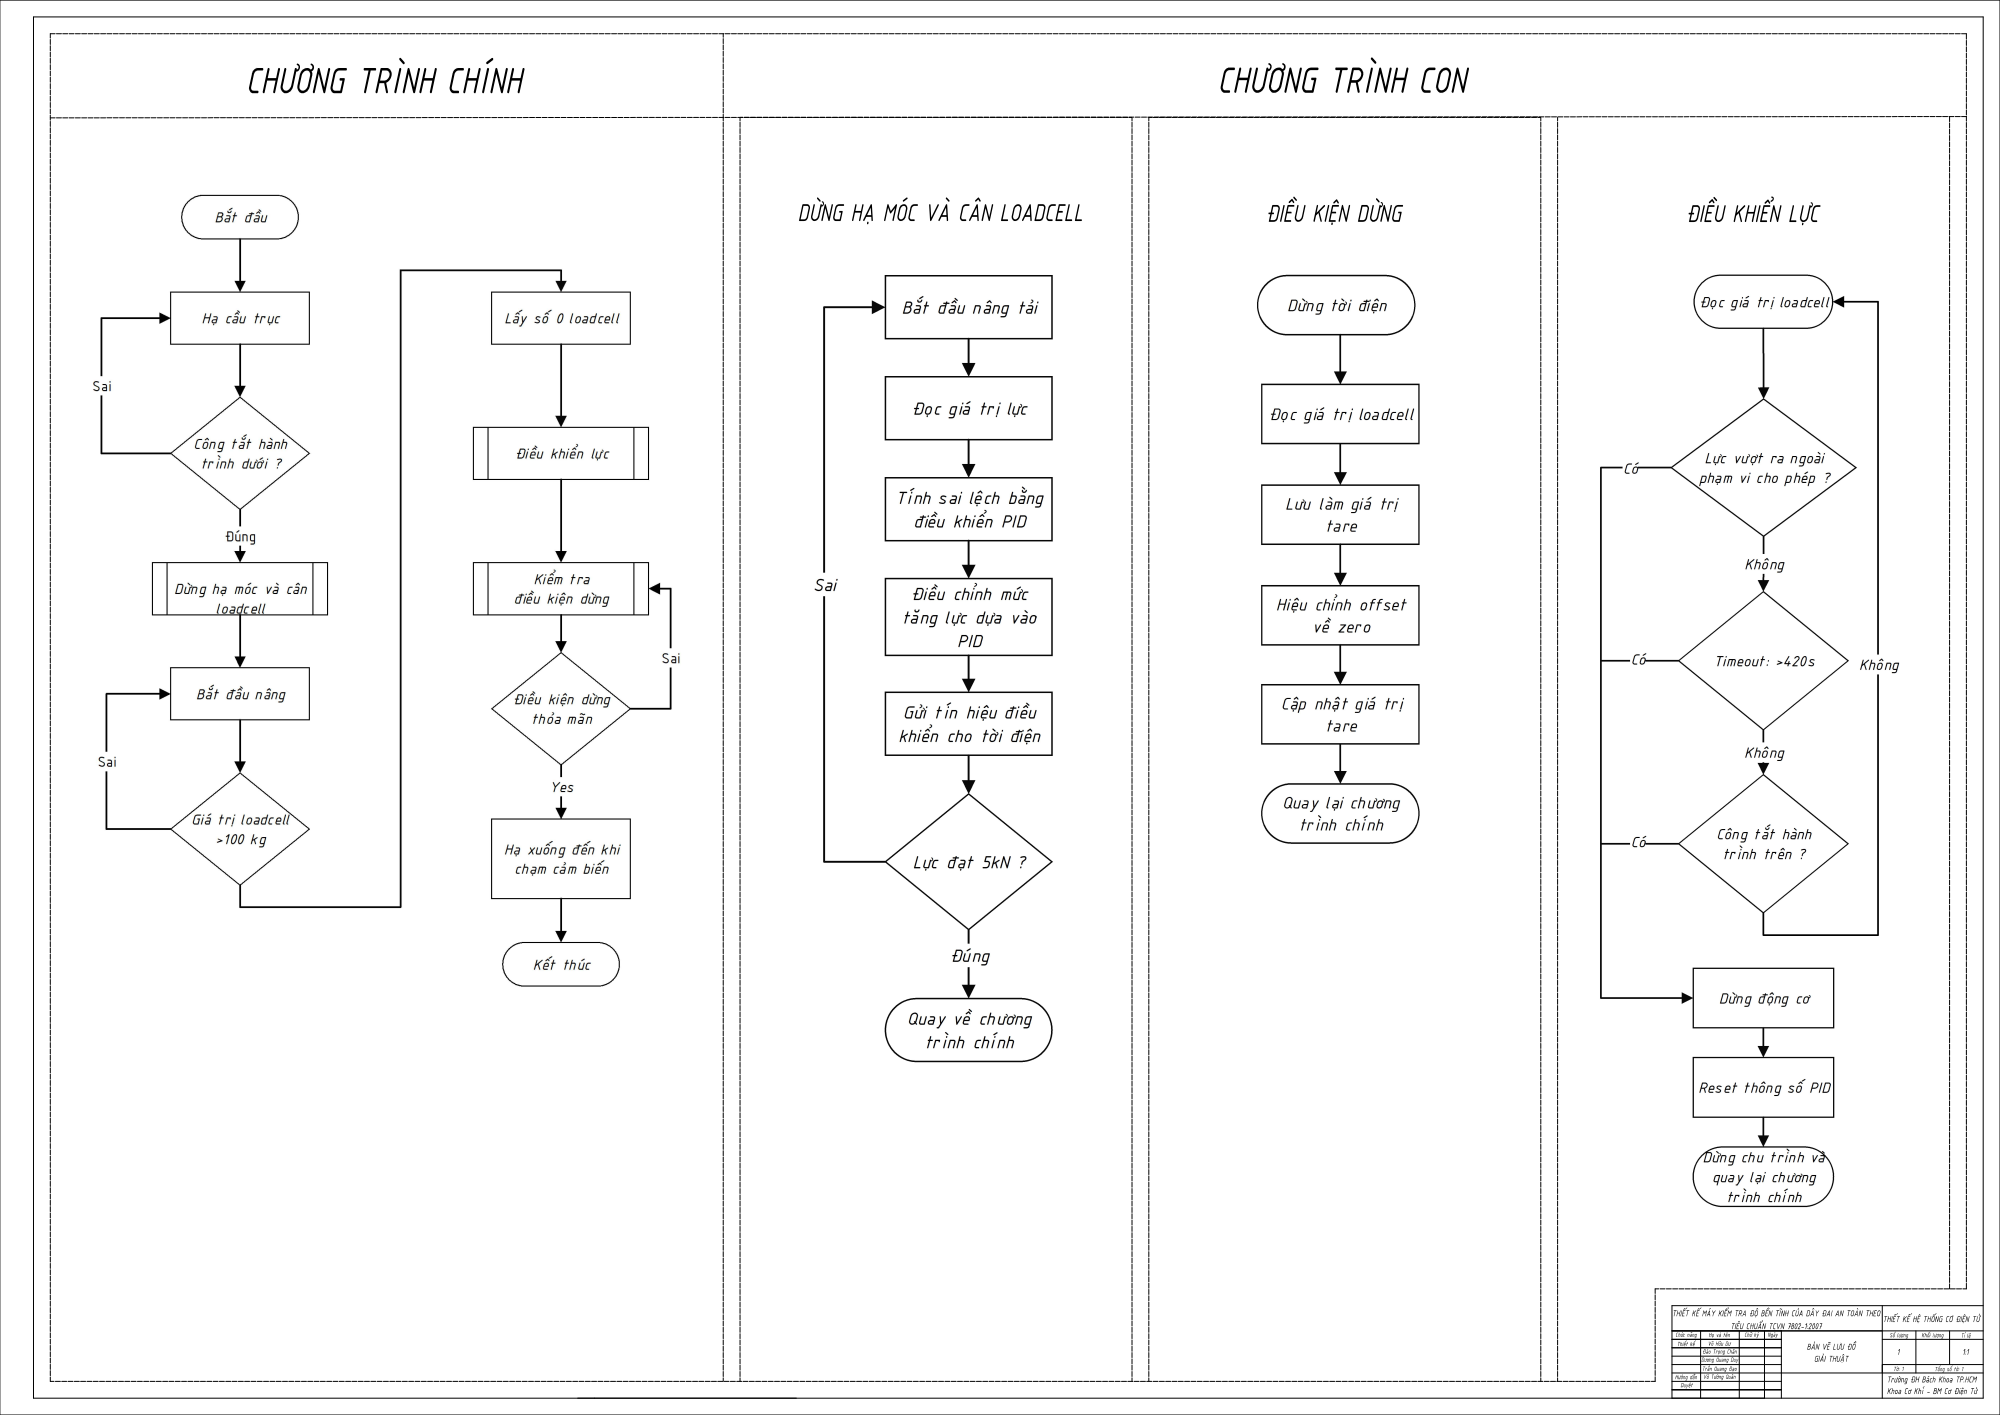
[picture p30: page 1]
Họ và tên; Chữ ký; Ngày; Số lượng; Khối lượng; Tổng số tờ: 1 1 Trường ĐH Bách Khoa TP.HCM; CHƯƠNG TRÌNH CHÍNH; CHƯƠNG TRÌNH CON; DỪNG HẠ MÓC VÀ CÂN LOADCELL; ĐIỀU KIỆN DỪNG; ĐIỀU KHIỂN LỰC

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

Chức năng | TIÊU CHUẨN TCVN 7802-1:2007 Võ Hữu Dư Đào Trọng Chân | Khoa Cơ Khí - BM Cơ Điện Tử 1:1 BẢN VẼ LƯU ĐỒ GIẢI THUẬT

Thiết kế

Dương Quang Duy
Trần Quang Đạo

Hướng dẫn | Võ Tường Quân
Duyệt

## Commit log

2025-12-03 (Chapter4) Add drawing and modify algorithms
    [Algorithms_Drawing.dwg]
2025-12-03 Fix bug on master
    [Algorithms_Drawing.dwg]
2025-12-03 Bo sung ban ve dien
    [Electrical_Drawing.dwg]
2025-12-03 Change algorithms drawing
    [Algorithms_Drawing.dwg]
2025-12-04 UPDATE DRAWING
    [Mechanical_Drawing.dwg]
